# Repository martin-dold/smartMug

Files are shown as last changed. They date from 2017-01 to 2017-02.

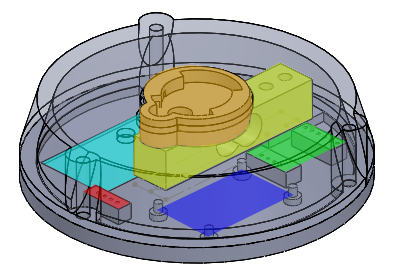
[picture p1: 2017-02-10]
development/src/sensor/3d_modell Kopie.png

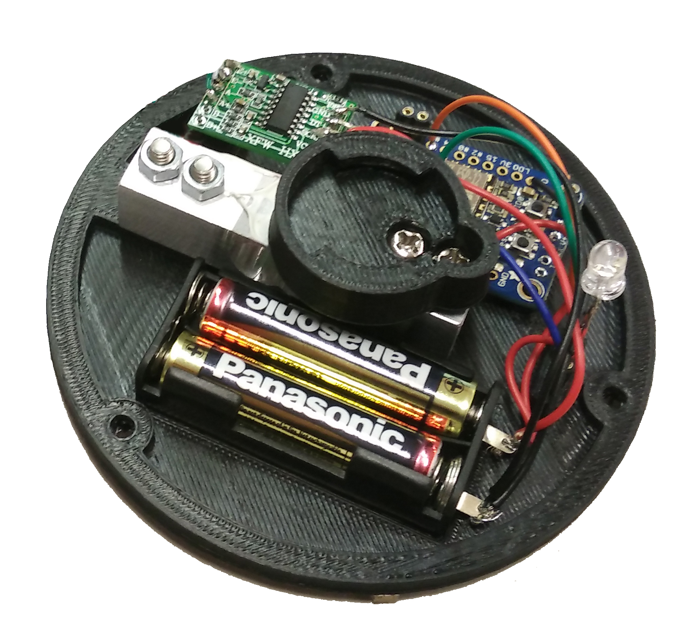
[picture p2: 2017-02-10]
Organization/SequenceDiagram/IMG_20170131_155303 Kopie.jpg

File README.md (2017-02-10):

# SmartMug
This is the repository for the SmartMug project.

The intention of the project is to turn a standard mug into a SmartMug by mounting the developed
SmartMug case on the bottom of the mug.
Using the developed Android App, the user can now connect to his mug.
Once the wireless connection is established, the following services are available:

- Ordering via app: the SmartMug changes its color to signal the waitress
that the user wants a new drink, reorder the same drink, asks for the bill or has no request at all.
- Monitor the current filling level of the mug within the app.
- Play two different drinking games.
- Entering personal data to display user statistics, e.g. blood alcohol level.

# Project Startup and History

This chapter describes initial considerations at project startup that finally lead to the developed SmartMug.
The documentation of the latest release starts in section [Architecture](#architecture).

## Initial Research and Related Work

At start of the project, the team started research on smart mug applications and required technologies.
Besides others, the task was to address the following two main questions:

- Do applications regarding smart liquid level sensing already exist?
- Which technology can be used for smart liquid level sensing?

With regards to the first question, two interesting papers are found.

The project **"Lover's cup"** [1] connects two spatially separated cups via wireless network to the internet.
This remote connection "enable people to share the time of drinking with someone they care about in different places.
Using a wireless connection, an otherwise ordinary pair of cups becomes a communication device,
amplifying the social aspect of drinking behavior" [1].
However, the focus of the paper is the social aspect of drinking rather than the technologies required to build the device.

The project **"Wireless Liquid Level Sensing for Restaurant Applications"** [4] is more of interest for the SmartMug project
as it targets a similar application: "Since restaurants often make much of their profits on drinks, it is critical for servers
to offer refills in a timely fashion. We propose wireless liquid level sensing glassware to aid in this task." [4]
Though the motivation for the project is a more economical aspect, the paper describes
the technologies and especially the liquid level sensing in detail. This project solved the liquid level sensing by
capacitive sensing.
In fact, the paper aims to the same application as the SmartMug.
However, the project was founded in 2002 and technologies vastly enhanced since then. This is the main reason to still
develop the SmartMug using state-of-the-art technologies like low-power optimized wireless modules and smartphones.

With regards to the question about liquid level sensing, the research identified:

- In industry, the focus relies on measuring the liquid flow into or from a container whenever possible rather than measuring the
level of the container itself. Examples are pipette in biology or dosing pumps as medical devices.
- If the liquid level shall be measured within the container, a floating gauge is typically used, e.g. like in car tanks.
However, this solution does not fit to the SmartMug project because of hygienic reasons and general user acceptance as
drinking the liquid in the SmartMug shall be possible and nobody expects a floating gauge in his or her drink.
- An appropriate technology is used by the project **"Wireless Liquid Level Sensing for Restaurant Applications"** [4]
that uses capacitive sensing. Additionally, two application reports give detailed insight into this technology [2] [3].
- If the weight of the mug is known in advance, the liquid level can be measured by weighting the mug including the liquid.
The SmartMug project finally used this technology.

## Hardware and Software Selection
One of the first steps at project startup was to define the required hardware and software components.
Constraints are:

- A wireless protocol that fits for battery powered nodes.
- A wireless protocol that allows a huge number of nodes within network, as there are a lot of mugs within a restaurant or bar.
- A wireless communication module that allows a battery powered application to be attached to the mug.
It should be possible to easily run the previously defined wireless protocol.
- The SmartMug user should easily connect to its mug, even with its own smartphone.

### Wireless Protocol

In the very first evaluation step, the following wireless protocols were considered:

1. IEEE802.11 Wireless LAN 
2. IEEE802.15.4 Zigbee
3. Bluetooth (Low Energy)
4. 6LoWPAN

The Zigbee as well as the 6LoWPAN protocol fit very well with regards to the power consumption constrain:
Both protocols are specialized for battery powered nodes as they both are designed for this application purpose.
Drawback of these protocols is the missing connection to the users smartphone: 
By default, none of these protocols are supported by any state-of-the-art smartphone, that typically supports Wireless LAN and Bluetooth.
Therefore, communication to the smartphone requires a gateway node that forwards messages between the 
SmartMug and the smartphone.
Due to this disadvantage of requiring an additionally device for network translation,
the protocols Bluetooth and Wireless LAN are short-listed.

Finally, the focus changed to Wireless LAN as:

- it is fully supported by almost all smartphones, even older ones,
- it easily allows to run well-known protocols such as TCP/IP or UDP on top for applications data exchange,
- it allows a huge number of mugs to be connected to the same network,
- a lot of today's restaurants and bars already provide a Wireless LAN network to the customers.
This would allow to reuse existing restaurant infrastructure for future SmartMug services directly connected to the bar.
- the universities laboratory provides a Wireless LAN module in-house that states promising power consumption in the documentation.

### Wireless LAN module

As a result, the low-power Wireless module [ESP8266](http://espressif.com/en/products/hardware/esp8266ex/resources "ESP8266") was chosen.
It meets the low-power requirement, has sufficient GPIO pins for the connection to the liquid level sensing unit 
and provides a huge variety of software development kits (SDK), e.g. NodeMCU (Lua-based), Arduino and MicroPython.
A full list of available SDKs is available [here](http://www.mikrocontroller.net/articles/ESP8266 "ESP8266 SDKs").

In the end, Arduino was chosen as it is open-source and provides full library support for Wireless LAN, TCP/IP, Multicast DNS
and even for the HX711 load cell that was chosen for liquid level sensing.

### Smartphone App

To allow the SmartMug user to connect to the mug, a smartphone app shall be developed. 
For the first prototypes, it was defined to develop an app for Android smartphones.
Development of an iPhone app was seen as future extension to the project.

# Source Code Documentation
The source documentation is hosted on GitHub pages.
Click [here](https://martin-dold.github.io/smartMug/ "Source Code Documentation") to browse the source code documentation.

# Architecture
Within this project the following components are involved:

- **Mug**: Usual mug that holds your drink.
- **SmartMug**: Extension to your make your mug smart.
- **Android app**: Connects to your SmartMug and provides the service(s).
- **Wifi access**: SmartMug and Android App require a Wireless LAN network to communicate.

## Liquid Level Sensing

Initially there were two different approaches for liquid level sensing. Finally the decision was pro weight measurement, because:

- Capacitive measurement requires bent or flexible copper plates to be mounted on a circular surface. This material was not available in a suitable amount time. 
- At the beginning the team was not sure, if such a circuit could be developed in time.

The chosen method of liquid level sensing is weight measurement. This task is accomplished by a load cell, an amplifier and an analog-to-digital converter.

- **load cell**: Contains four strain gauges, that build a Wheatstone Bridge. The differential output voltage can be measured by an amplifier.
- **HX711**: Uses a built in amplifier and ADC. No further circuits are required.

## Arduino

Wireless module [ESP8266](http://espressif.com/en/products/hardware/esp8266ex/resources "ESP8266") 
is programmed using open-source Arduino SDK. The firmware is composed of several Arduino files.
Each of them contains a separate software unit/module. 
For a complete list of software modules and its implementation details, check out the Arduino chapter
of the [Source Code Documentation](https://martin-dold.github.io/smartMug/ "Source Code Documentation").

Most important software modules are:

- **Wifi:**  
Uses Arduino ESP8266 Wifi library to establish a Wifi connection.
After startup, the SmartMug scans its environment for the Wireless LAN SSID "*smartmug*". A password for WPA2 is required.
- **TCP:**  
Uses Arduino TCP library to create a server socket and listen on TCP port 8080 for incoming connection requests.
- **HX711:**  
Uses HX711 library to measure the weight using HX711 load cell.
- **Over-the-air Update:**  
Uses Arduino ESP8266 OTA library to provide firmware update over-the-air.

### Pin configuration and functions

The following table lists the pins that are connected to the microcontroller.

| Pin | Function |
| --- |:---:|
| 13 | RGB-LED Red |
| 5 | RGB-LED Green |
| 12 | RGB-LED Blue |
| 14 | HX711 scale: DOUT |
| 16 | HX711 scale: PD_SCK |
| 21 | UART Tx data |
| 22 | UART Rx data |

## Android App

This section contains a brief overview of the Android App architecture and its main features.
For more details check out the [Source Code Documentation](#source-code-documentation).

- Target API level: 24.
- Android version: 7.
- Architecture of the SmartMug App, first view is Main Activity:
    - Connection to Mug activity -> build connection to SmartMug via manuell input of the IP address or via bar code scanner.
    - Statistics activity -> collects statical data of the user.
    - Order activity -> allows to call the waitress, reorder the same drink or ask for the bill.
    - Personal Data activity -> allows the user to enter personal data information to calculate statistics like blood alcohol level.
    - Games activity -> allows to the user to play drinking games.
    - TCPClient class -> create new TCP Connection for sending (e.g. re-order) and receiving (e.g. filling level).
    - MugContent class -> handle received messages from the SmartMug.
    - NSDHelper class -> scans the network for smartmug mug services using mDNS.

## SmartMug case manufacturing

The case manufacturing contains two main tasks namely the case itself and the mounting parts, that are connecting the actual mug with the load cell. All the parts are modelled in SolidWorks 2013 and are printed via the MakerBot Replicator X2 3D-printer.

The case itself has a bottom part, where all the components are mounted. The mounted elements are:
- Load Cell
- Adafruit Huzzah ESP8266 microcontroller
- Hx711 ADC and Amplifier
- RGB LED
- Battery case for AA batteries.

The second part is a bayonet mount, with a female and a male part. These are used to connect the mug the load cell.

# Communication

This chapter explains the communication schemes and protocols that are used within this project.

## TCP/IP

The communication between the SmartMug and the Android App is based on TCP/IP using Wireless LAN according to IEEE802.11b/g standard.
Therefore, the Android device and the SmartMug must be connected to the same wireless network to allow communication between both.

The SmartMug acts as TCP server that is continuously waiting for incoming connections right after startup.
Once a TCP connection is established successfully, the mug provides updated liquid level values once a second.
The mug publishes its service to the network using [Multicast DNS](#multicast-dns).

The Android App acts as TCP client connecting to the SmartMug.

## Multicast DNS

The SmartMug publishes its service through "Multicast DNS" (mDNS) including the following properties:

- *Service name*: smartmug
- *Service type*: \_smartmug.\_tcp

The Android App is listening for providers of the smartmug service type. Using the identifier read from the SmartMug bar code,
the app is able to select the correct mug to connect to out of the list of available mugs within the network.

## SmartMug Protocol

The SmartMug Protocol is invented for bidirectional communication between the SmartMug and the Android App. It is used on top of the TCP protocol to format the byte stream.
It follows the basic principle of < TAG >< LEN >< Value > and is implemented as shown in the following graph:

```
+-----------+------------+----------------+----------------+
|           |            |                |                |
|    TAG    |   Length   |      Value     |  End of Frame  |
|           |            |                |                |
+-----------+------------+----------------+----------------+

   1 byte       1 byte        n bytes           1 byte
```

Multi-byte fields are transported with most significant byte (MSB) first.

The following tags are currently defined:

- Tag = **0x01**: (SmartMug to Android App)  
  Sensor Data: Weight (in gram)
- Tag = **0x02**: (Android App to SmartMug)  
  LED Set Color using color codes transported as value:  
  - Off:   0
  - Red:   1
  - Green: 2
  - Blue:  3
  - White: 4
- Tag = **0x03**: (Android App to SmartMug)  
  Tare SmartMug scale to '0'

Accordingly, an example of a sensor data frame is:

```
+-----------+------------+----------------+----------------+
|           |            |                |                |
|   0x01    |    0x02    |     0x017A     |      0x0A      |
|           |            |                |                |
+-----------+------------+----------------+----------------+

   Sensor       Length          378g             '\n'
    Data
```

# Outlook

This chapter lists further features and ideas in general that can be added to the project.

## Connect to the Restaurant

A connection between SmartMug and the restaurant would allow the barkeeper to monitor the customers mugs using live data, i.e.
the barkeeper is able to detect when to serve which guest based on the SmartMug data.
Furthermore, this allows the customer to directly place an order to the barkeeper via wireless connection.

## Payment via SmartMug App

Once the connection to the restaurant is established, one may advance the SmartMug App to allow a digital payment method for the drinks.

## Health monitoring

The data the SmartMug App currently collects (sex, weight and total amount of liquid) allows to offer further services like health monitoring.
The SmartMug App can detect when the user did not drink for some hours and can give warnings to ensure that a patient drinks enough liquid during a day.

## Security

The current security mechanism relies on the encryption mechanism used by the wireless network (e.g. WPA2) both Android app and SmartMug are connected to.
The communication between the SmartMug and the app is neither authenticated nor secured on a higher level.
A new feature might be using a TLS protected channel or (at least) an AES encrypted communication between the devices.
However, it should be considered that TLS is heavy computational work for small microcontrollers.
This holds true especially for battery powered device like the SmartMug.
Computing TLS sessions will surely have an impact on the battery life time of a SmartMug.
Still, AES encryption is state-of-the-art even for small microcontrollers as HW acceleration is feasible and allows to
reduce power consumption for battery powered devices.

Therefore, application layer security using AES encryption appears reasonable.

# References

- [1] Lover’s Cups: Drinking Interfaces as New Communication Channels, Chung et al., 2006, [Link](http://dl.acm.org/citation.cfm?id=1125532&dl=ACM&coll=DL&CFID=725409781&CFTOKEN=29915740 "Link to Paper")
- [2] Ultrasonic Sensing Basics for Liquid Level Sensing, Flow Sensing, and Fluid Identification Applications,  
Texas Instruments, 2015, [Link](http://www.ti.com/lit/an/snaa220a/snaa220a.pdf "Link to PDF")
- [3] FDC1004: Basics of Capacitive Sensing and Applications, Texas instruments, 2014, [Link](http://www.ti.com/lit/an/snoa927/snoa927.pdf "Link to PDF")
- [4] Wireless Liquid Level Sensing for Restaurant Applications, Dietz et al., 2002, [Link](http://www.merl.com/publications/docs/TR2002-21.pdf "Link to Paper")
- [5] Datasheet of Hx711 [Link] (http://www.ti.com/lit/an/snoa927/snoa927.pdf "Link to datasheet")

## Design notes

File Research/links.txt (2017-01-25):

https://www.teco.edu/research/mediacup/

Hier mal etwas interessantes:
http://www.merl.com/publications/docs/TR2002-21.pdf

-> "Capacitive Sensing" klingt ziemlich interessant.

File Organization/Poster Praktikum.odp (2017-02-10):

## SmartMug The clever way to order

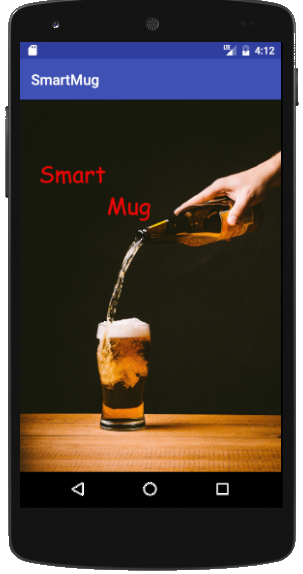
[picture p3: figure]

  Martin Dold, Larraitz Orio,
  Gürkan Karacocuk, Dennis Tritschler

Architecture

Android App: Connects to the SmartMug

Wifi access: Wireless Communication

Mug: Standard Mug

Smart Mug: Extension to make your mug smart

Functions

Connection to mug via bar code reading

Liquid level sensing via weight (HX711 circuit)

Drinking statistic analysis via app

Interactive drinking games via app

Waitress communication by changing mug color

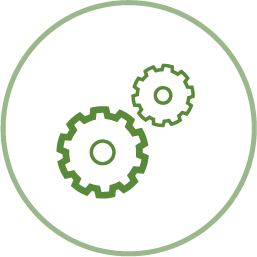
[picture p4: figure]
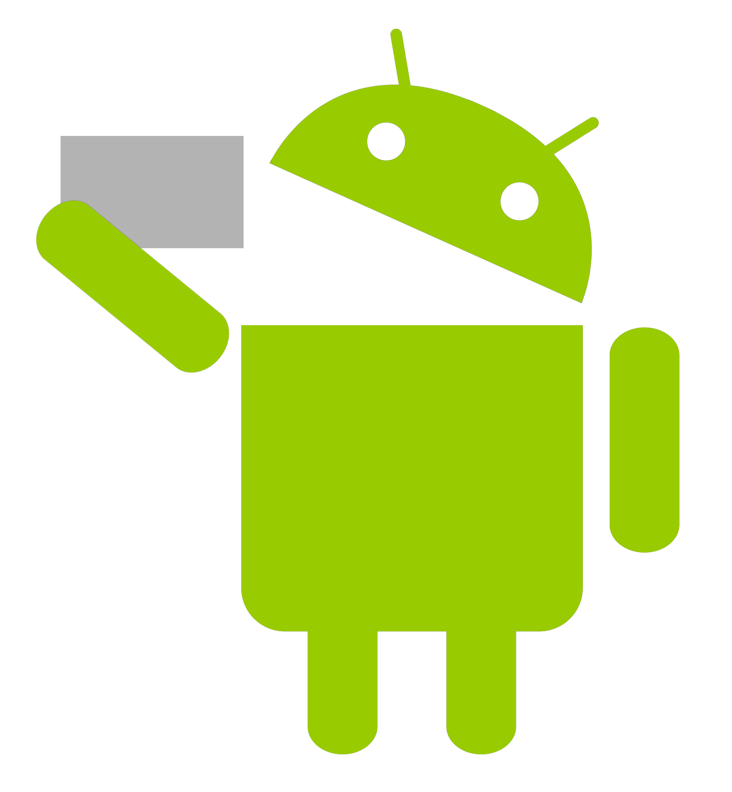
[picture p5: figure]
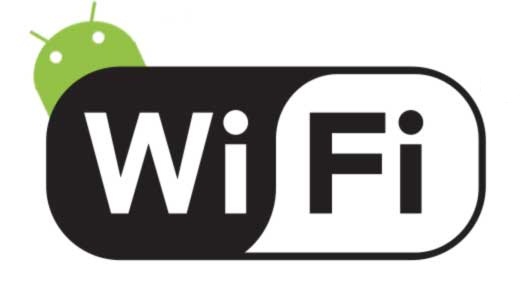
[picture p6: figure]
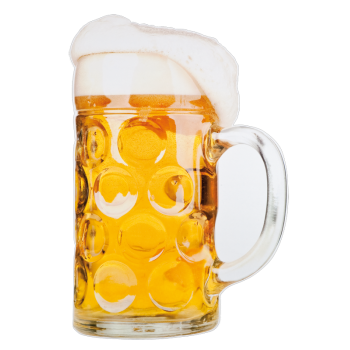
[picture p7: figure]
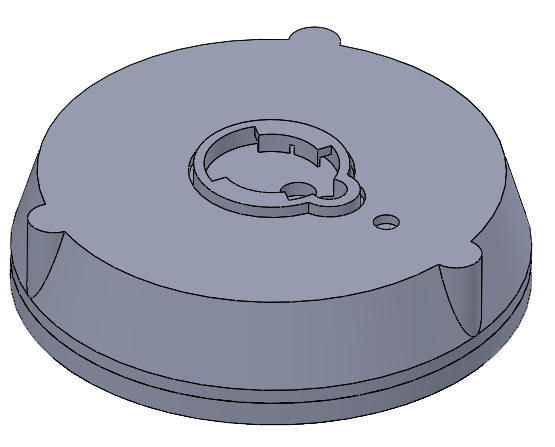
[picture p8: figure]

SmartMug

SmartMug App

HX711

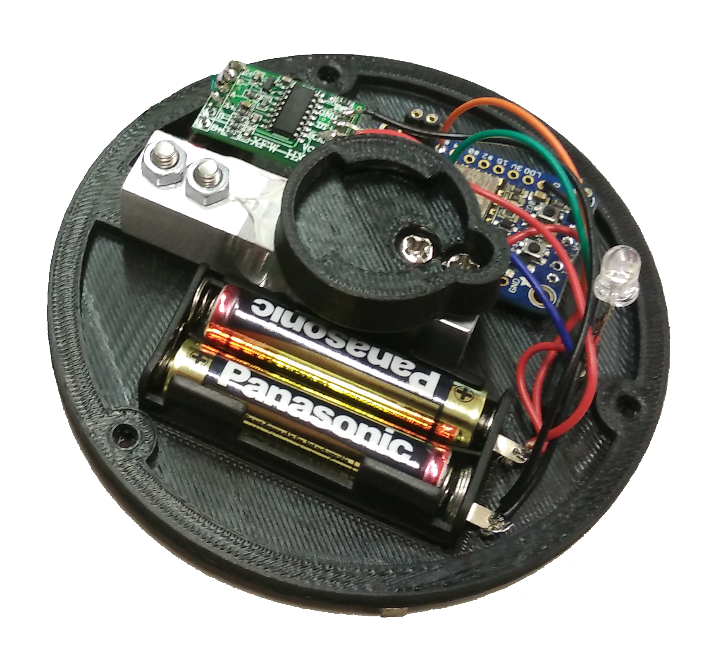
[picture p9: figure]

Bayonet mount

Connect to your

SmartMug via Bar Code

or by entering

manuell the IP Adress

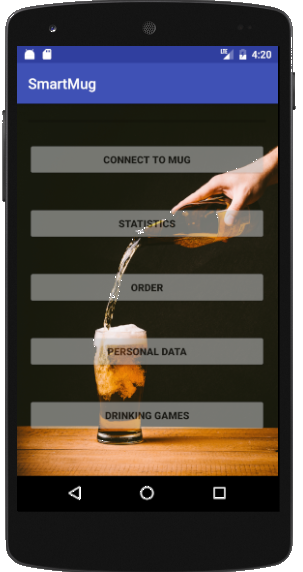
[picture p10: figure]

Load cell

Adafruit Huzzah

Display some

statistics like promile

RGB-LED

Batteries

Enter your personal Data

for some statistics


Order via SmartMug

Case

Play some drinking

games

Connection

SmartMug Protocol

TCP/IP → Wireless LAN according to

IEEE802.11b/g standard

Multicast DNS:

Service name: smartmug

Service type: _smartmug._tcp

Tag 1byte | Length 1byte | Value n bytes | End of Frame 1 byte

Sequence diagram

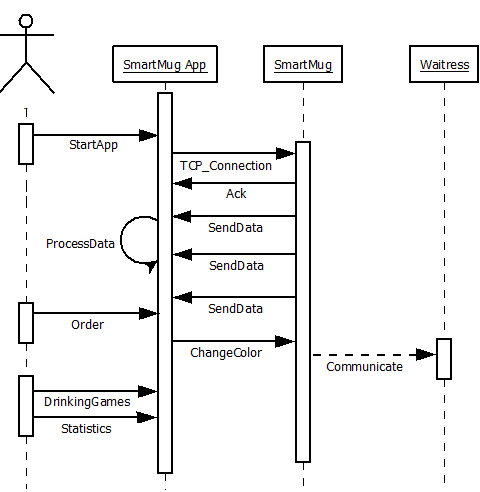
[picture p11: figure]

Outlook

- Connection to the barkeeper → Live data for the barkeeper, direct re-order function

- Payment via app

- Capacitive measurement instead of weight

- Connection between taps and SmartMug for automated and exact measurement of the filling level

More Details under:

https://github.com/martin-dold/smartMug

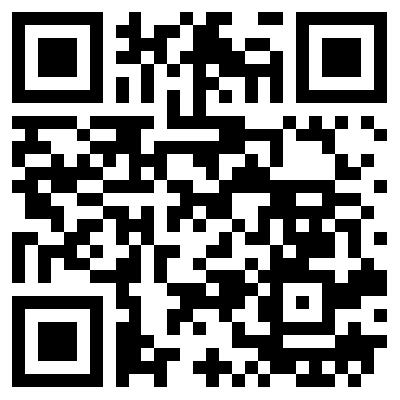
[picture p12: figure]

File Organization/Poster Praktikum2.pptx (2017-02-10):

## SmartMug The smart way of drinking


- Martin Dold, Larraitz Orio,
- Gürkan Karacocuk, Dennis Tritschler

Architecture
Android App: Connects to the SmartMug
Wifi access: Wireless Communication
Mug: Standard Mug
Smart mug: Extension to make your mug smart

Functions
Connection to mug via bar code reading
Liquid level sensing via weight (HX711 circuit)
Drinking statistic analysis via app
Interactive drinking games via app
Waitress communication by changing mug color

SmartMug

HX711

SmartMug App

Batteries

Load cell


Bayonet mount


RGB-LED

ESP8266 module

Glass fill level

Connect to SmartMug
via Bar Code or by
entering the IP Adress

Enter your personal data
for some statistics

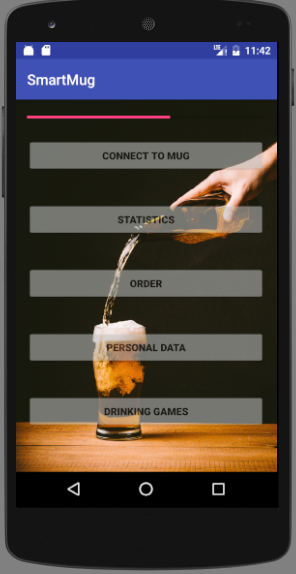
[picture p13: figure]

Display statistics
e.g. Blood alcohol level

Order via SmartMug

Case

Play drinking games

Connection
SmartMug Protocol
TCP/IP → Wireless LAN according to
IEEE802.11b/g standard
Multicast DNS:
Service name: smartmug
Service type: _smartmug._tcp

Tag 1byte | Length 1byte | Value n bytes | End of Frame 1 byte

Sequence diagram


Outlook
- Connection to the barkeeper → Live data for the barkeeper, direct re-order function
- Payment via app
- Capacitive measurement instead of weight
- Connection between taps and SmartMug for automated and exact meassuring of the filling level

More Details under:
https://github.com/martin-dold/smartMug


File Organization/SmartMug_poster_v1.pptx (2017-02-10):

## Smart Mug Don’t wait for drinks anymore

Martin Dold, Larraitz Orio,
Gürkan Karacocuk, Dennis Tritschler

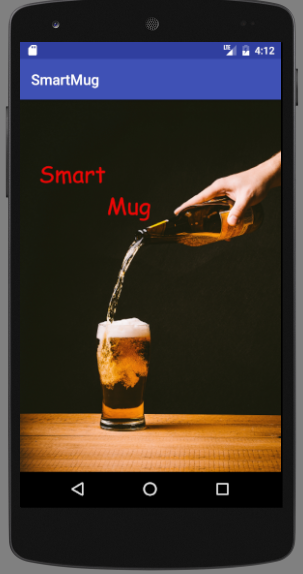
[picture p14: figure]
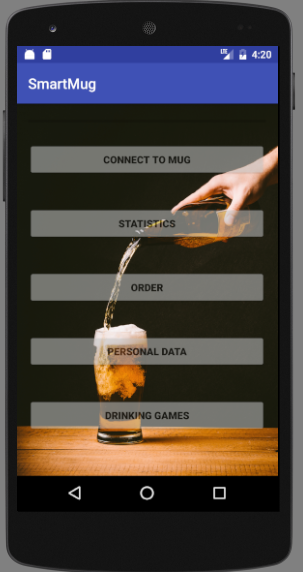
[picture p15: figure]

Outlook
- Connection to the Barkeeper
- Interactive Drinking Games
- Payment with app
- Capacitive measurement

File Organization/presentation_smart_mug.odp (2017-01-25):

## Smart Mug

Presentation 1: Concept

Dennis Tritschler, Guerkan Karacocuk, Martin Dold

Winter Term 2016

## Motivation

- I don't want to wait for the waiter/waitress to order new beer!

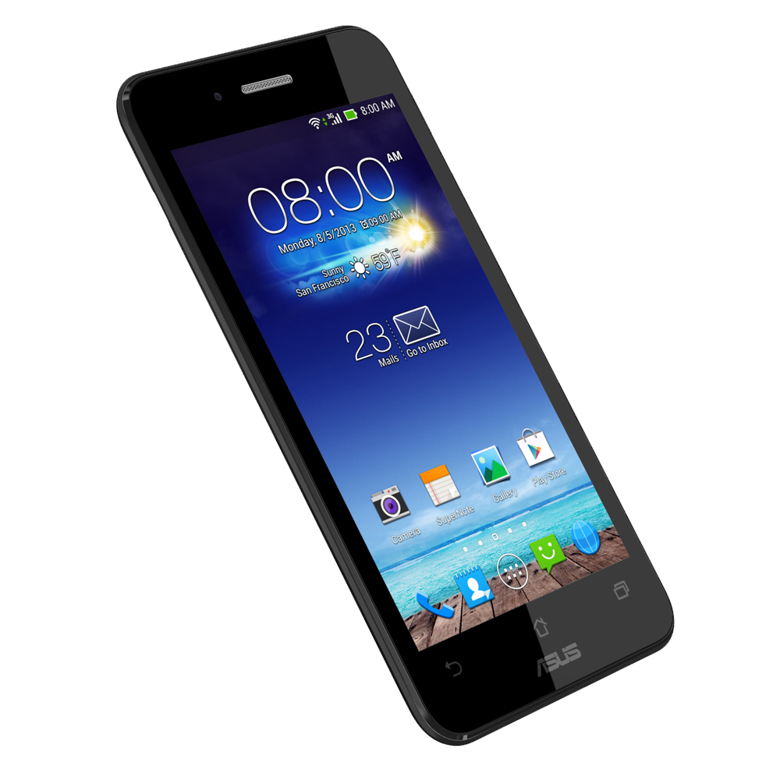
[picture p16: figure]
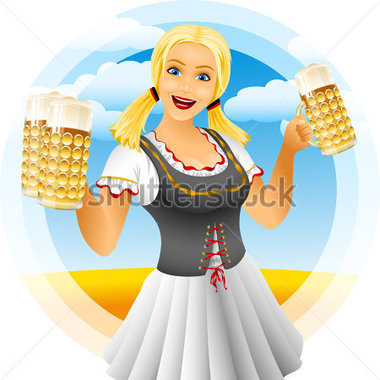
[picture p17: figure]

## Plan A

- Beer level sensing
  - By weight, by capacitive sensing, …
- Connect mug with smartphone
  - Bluetooth LE
  - Barcode, RFID
- Order by app and color of mug
- Live data for bar keeper
- Interactive drinking games

## Plan B

- Measure beer level
  - By weight, by capacitive sensing, …
- Connect mug with smartphone
  - Bluetooth LE
  - Entering mug ID into app
- Order by color of mug

## Plan C

- Connect mug with smartphone
  - Bluetooth LE
  - Entering mug ID into app
- Order by color of mug

## Plan D – Worst case

If neither wireless communication nor measurement works …

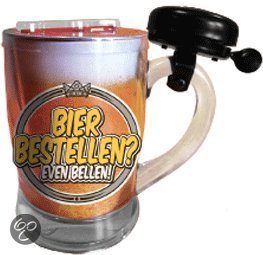
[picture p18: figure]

## Next steps / work plan

15.11. | Present (initial) selection of HW: - Sensor(s) - Bluetooth module
22.11. | Start SW implementation sensor reading, BLE connection Start HW schematic, layout
29.11. | Continue …
6.12. | Prepare for mid-term presentation: SW: sensor reading, BLE connection HW: schematic, layout ready

## Next steps / work plan

20.12. | First HW prototype ready
10.01. | Extend SW parts: order by app
17.01. | Extend SW parts: Connect to bar tender, display filling level
24.01. | Debugging / bug fixing
31.01. | Finalize debugging / bug fixing Report / Poster
07.02. | Project finalization

## Related work

- Wireless Liquid Level Sensing for Restaurant Applications (iGlassware)

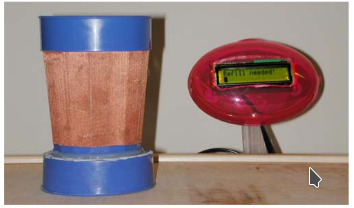
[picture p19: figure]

## Related work

- Lover’s Cups: Drinking Interfaces as New Communication Channels

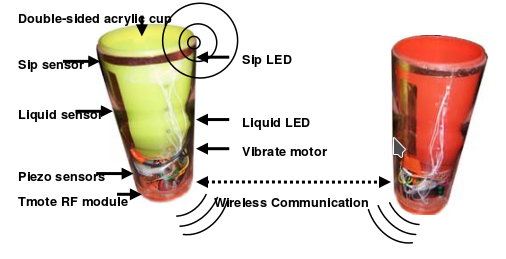
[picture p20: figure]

## Appendix

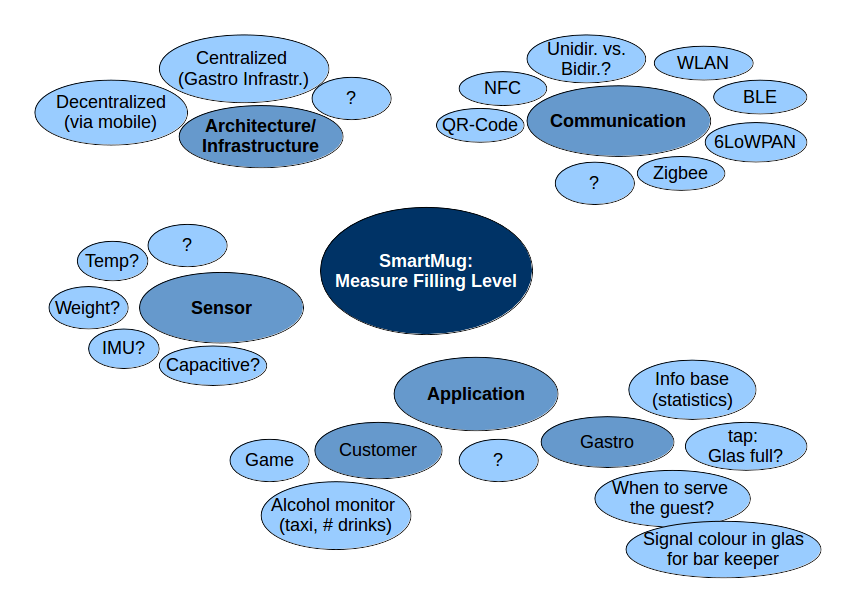
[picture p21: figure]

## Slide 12

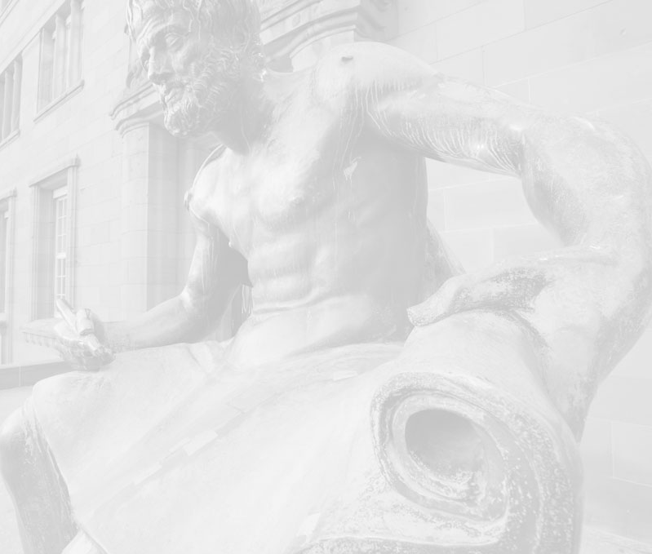
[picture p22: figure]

  Dieses Folienlayout bitte nur verwenden, um großformatige Abbildungen wie in diesem Beispiel zu zeigen.
  Es ist nicht für Texte etc. vorgesehen.

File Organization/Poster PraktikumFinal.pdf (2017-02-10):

# SmartMug

# The clever way to order

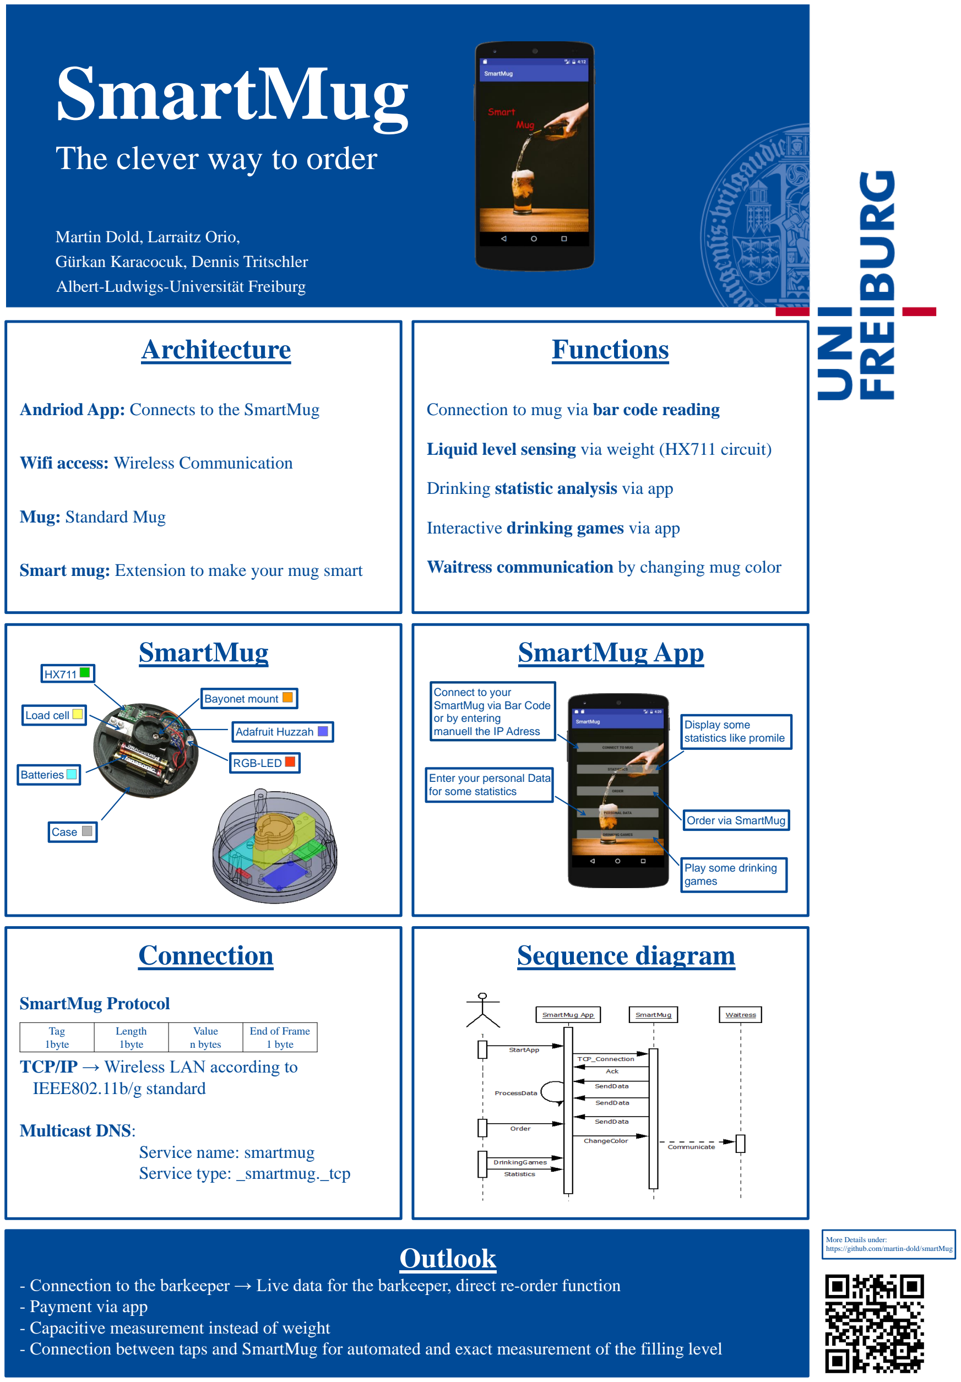
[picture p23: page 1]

Albert-Ludwigs-Universität Freiburg

## SmartMug

Martin Dold, Larraitz Orio,
Gürkan Karacocuk, Dennis Tritschler

## SmartMug App

## Connection

SmartMug Protocol

TCP/IP → Wireless LAN according to IEEE802.11b/g standard

Multicast DNS:
Service name: smartmug
Service type: _smartmug._tcp

## Sequence diagram

## Outlook

- Connection to the barkeeper → Live data for the barkeeper, direct re-order function
- Payment via app
- Capacitive measurement instead of weight
- Connection between taps and SmartMug for automated and exact measurement of the filling level

## Architecture

Andriod App: Connects to the SmartMug

Wifi access: Wireless Communication

Mug: Standard Mug

Smart mug: Extension to make your mug smart

## Functions

Connection to mug via bar code reading

Liquid level sensing via weight (HX711 circuit)

Drinking statistic analysis via app

Interactive drinking games via app

Waitress communication by changing mug color

Connect to your
SmartMug via Bar Code
or by entering
manuell the IP Adress

Order via SmartMug

Play some drinking
games

Display some
statistics like promile

Enter your personal Data
for some statistics

Bayonet mount
Load cell

HX711

Adafruit Huzzah

Batteries

RGB-LED

Case

More Details under:
https://github.com/martin-dold/smartMug

Tag
1byte

Length
1byte

Value
n bytes

End of Frame
1 byte

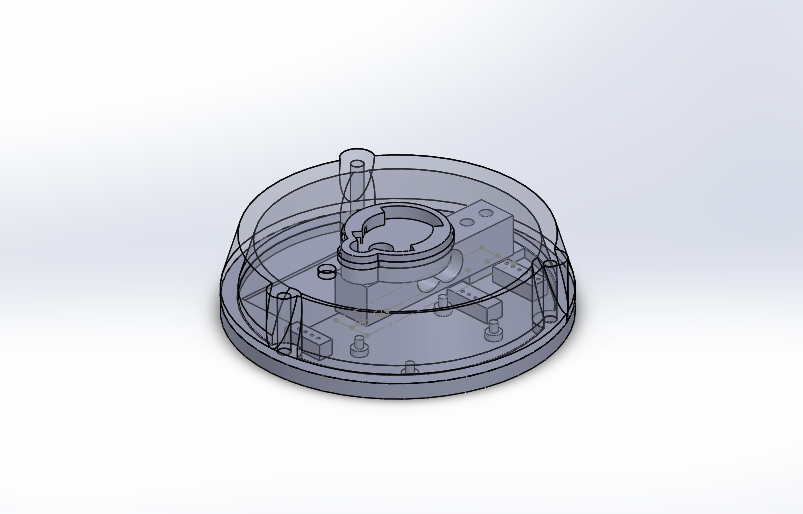
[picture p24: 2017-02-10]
development/src/sensor/3d_modell.PNG

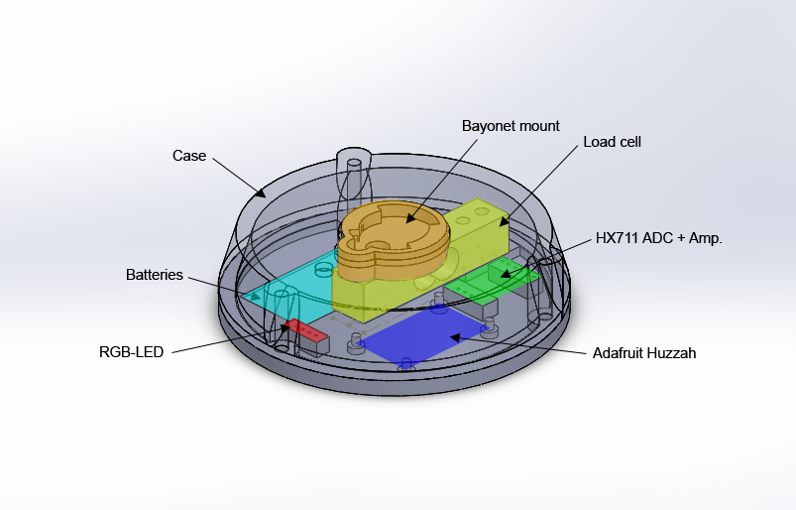
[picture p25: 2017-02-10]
development/src/sensor/3d_modell_gk.png

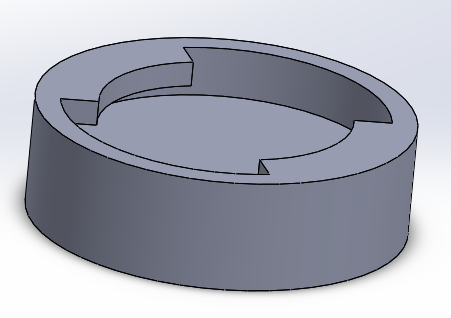
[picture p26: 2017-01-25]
development/src/sensor/gewinde/femalePart.PNG

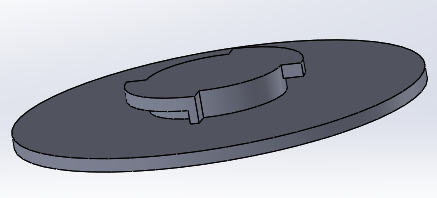
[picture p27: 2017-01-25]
development/src/sensor/gewinde/malePart.PNG

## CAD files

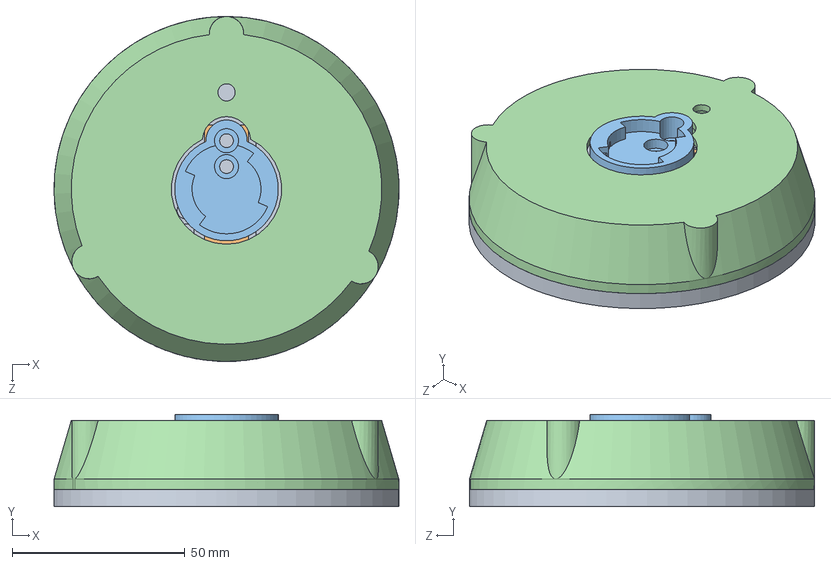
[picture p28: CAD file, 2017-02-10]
development/src/sensor/gehaeuse/gehaeuse.SLDASM
100.0 x 26.7 x 100.0 mm
boden
loadcell
femalePart2
deckel

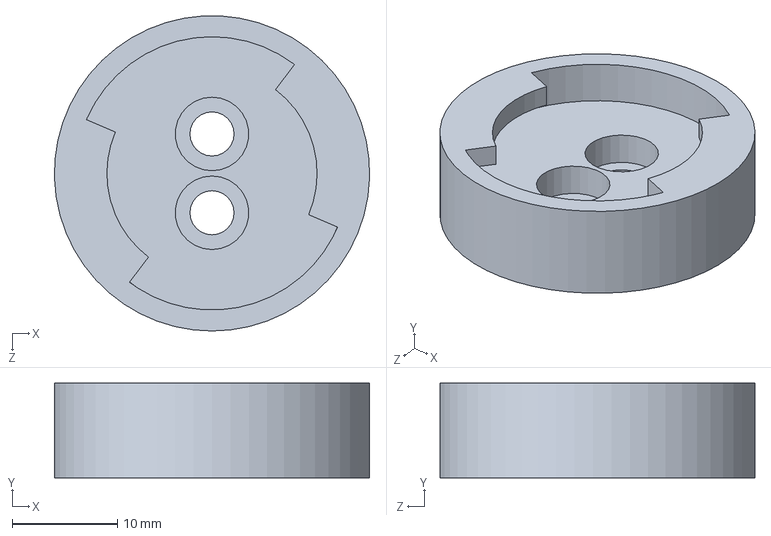
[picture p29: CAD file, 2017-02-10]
development/src/sensor/gewinde/femalePart.SLDPRT
30.0 x 9.00 x 30.0 mm

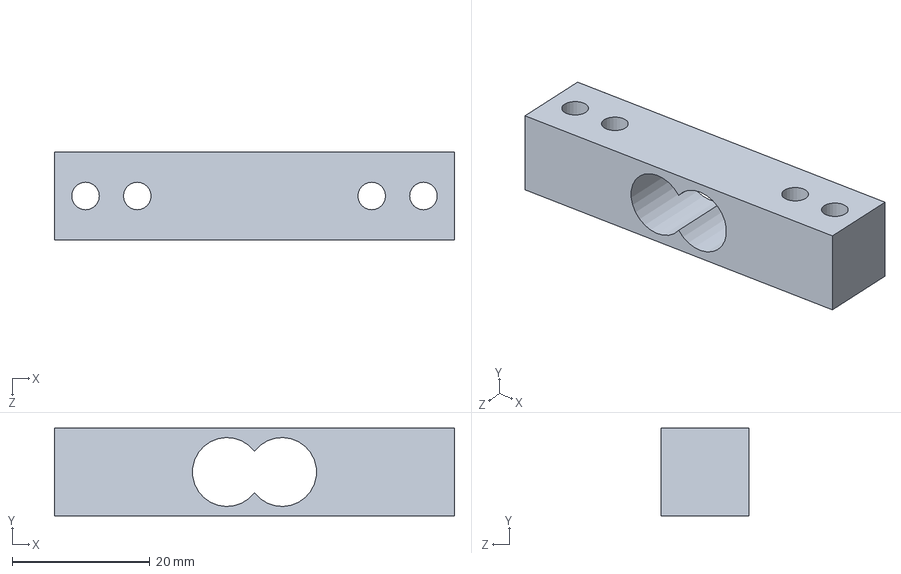
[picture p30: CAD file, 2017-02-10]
development/src/sensor/loadcell.SLDPRT
58.0 x 12.7 x 12.7 mm

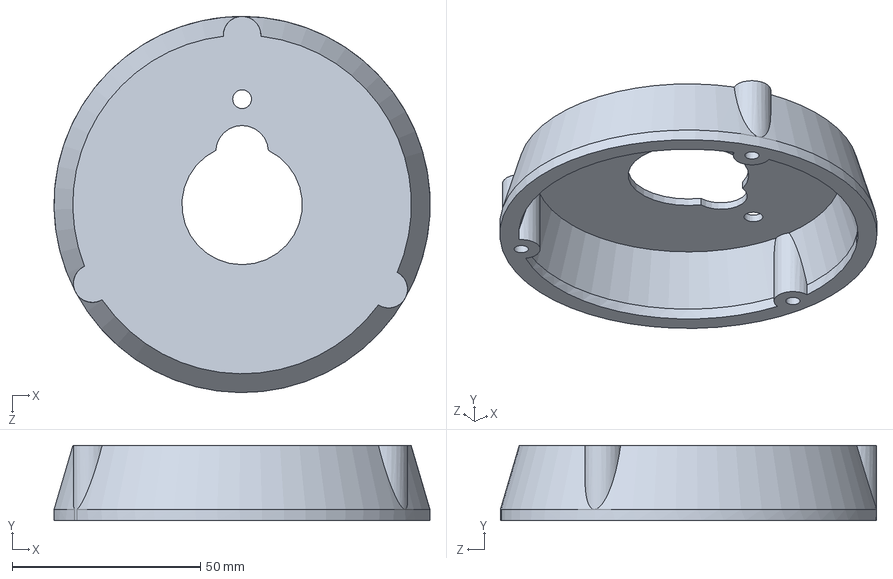
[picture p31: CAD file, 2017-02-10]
development/src/sensor/gehaeuse/deckel.SLDPRT
99.9 x 20.0 x 100.0 mm

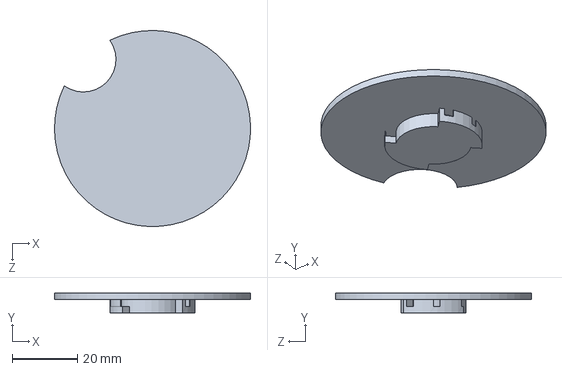
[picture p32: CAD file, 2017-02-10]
development/src/sensor/gewinde/malePart2.SLDPRT
60.0 x 6.00 x 60.0 mm

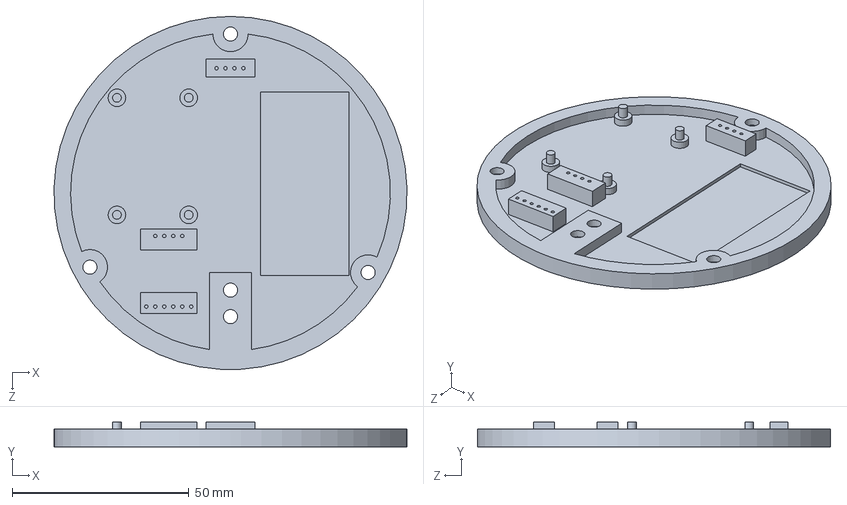
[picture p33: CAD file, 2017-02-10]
development/src/sensor/gehaeuse/boden.SLDPRT
100.0 x 7.00 x 100.0 mm

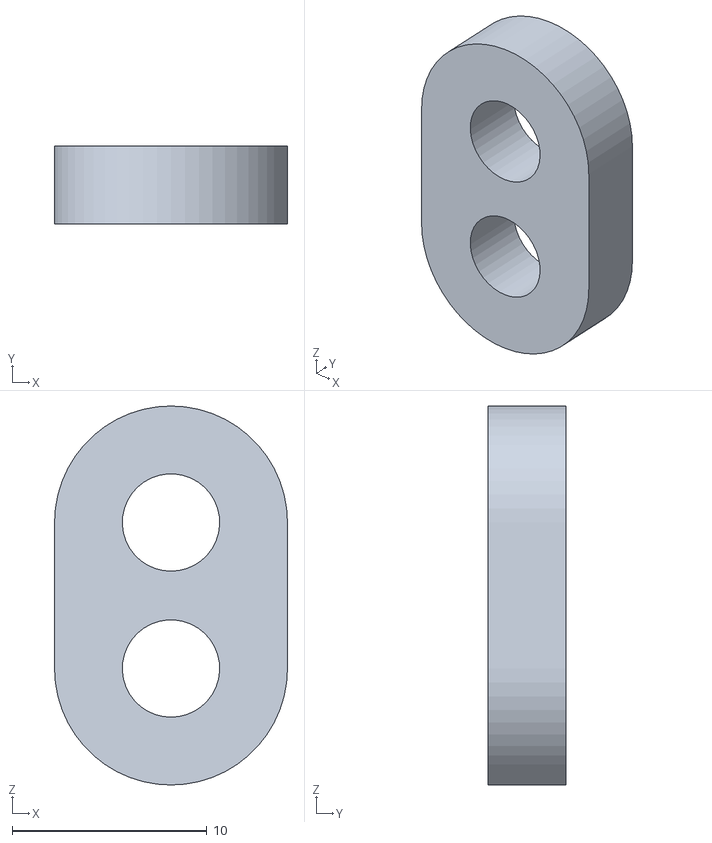
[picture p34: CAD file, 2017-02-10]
development/src/sensor/gewinde/Unterlagscheibe4.STL
12.0 x 4.00 x 19.5

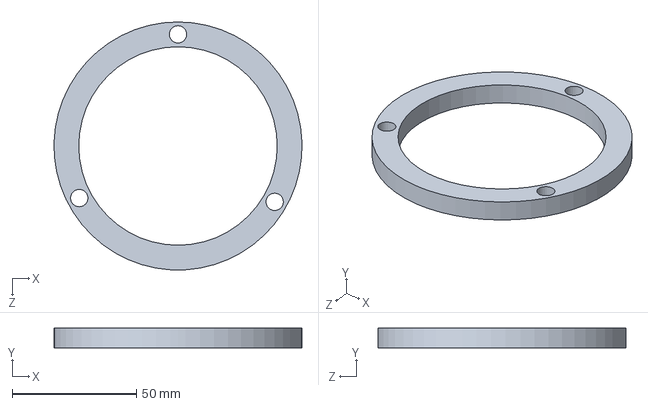
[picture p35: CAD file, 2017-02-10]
development/src/sensor/gehaeuse/ring.SLDPRT
100.0 x 8.00 x 100.0 mm

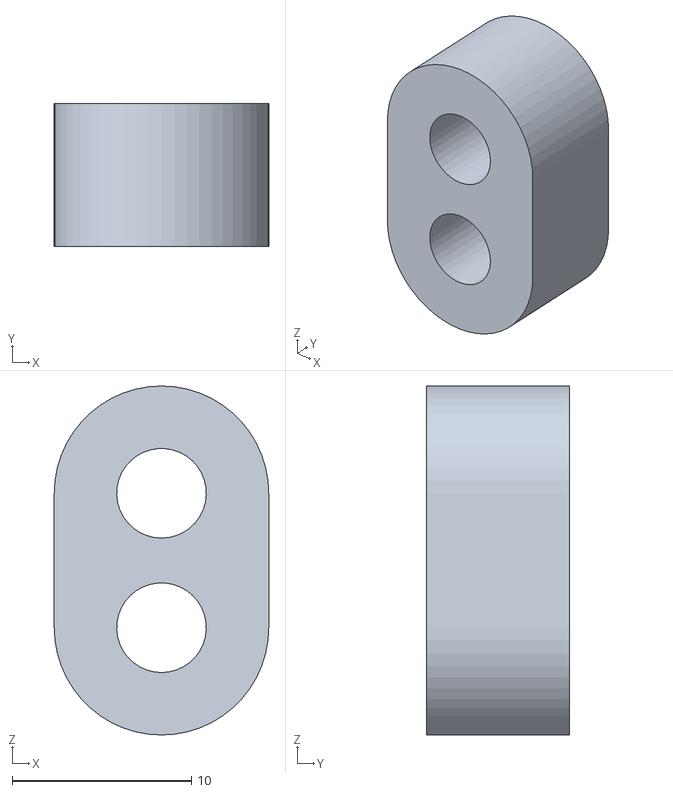
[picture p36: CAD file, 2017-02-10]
development/src/sensor/gewinde/Unterlagscheibe8.STL
12.0 x 8.00 x 19.5

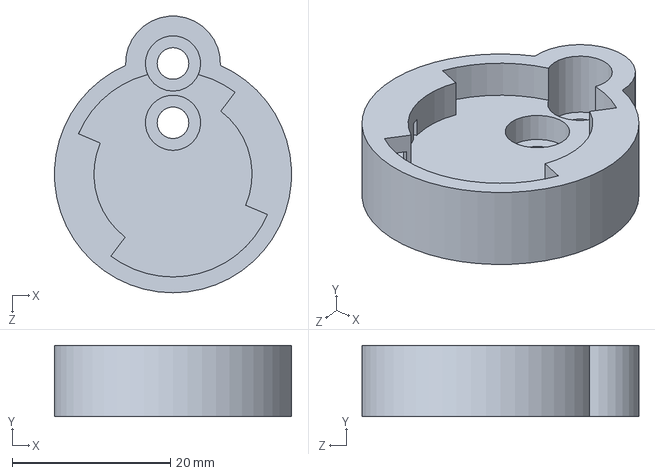
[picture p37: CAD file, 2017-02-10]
development/src/sensor/gewinde/femalePart2.SLDPRT
30.0 x 9.00 x 35.0 mm

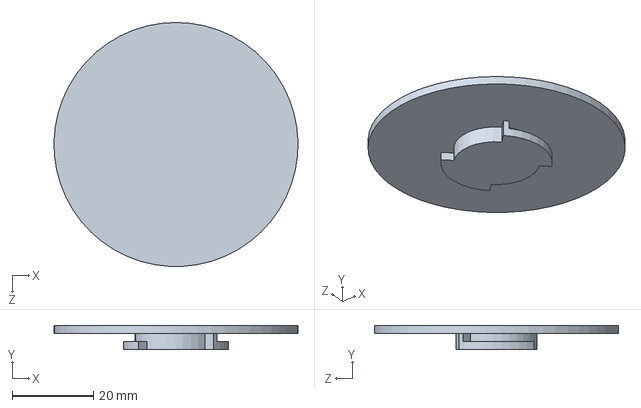
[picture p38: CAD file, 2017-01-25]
development/src/sensor/gewinde/malePart.SLDPRT
60.0 x 6.00 x 60.0 mm

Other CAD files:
development/src/sensor/gewinde/femalePart1.STL
development/src/sensor/gewinde/Unterlagscheibe.SLDPRT
development/src/sensor/gehaeuse/boden.STL
development/src/sensor/gehaeuse/deckel.STL
development/src/sensor/gehaeuse/ring.STL
development/src/sensor/gewinde/femalePart.STL
development/src/sensor/gewinde/femalePart2.STL
development/src/sensor/gewinde/malePart.STL
development/src/sensor/gewinde/malePart2.STL

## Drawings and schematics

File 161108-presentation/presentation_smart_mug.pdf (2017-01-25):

## Smart Mug

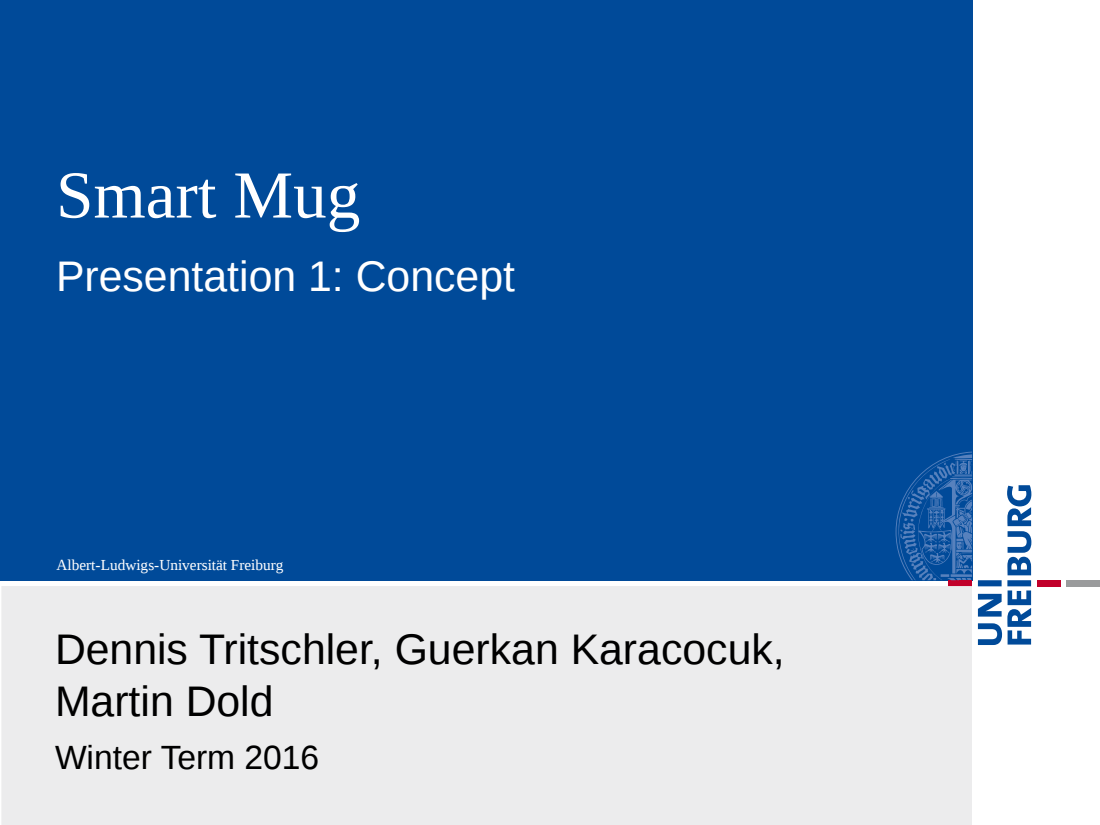
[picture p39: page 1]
Presentation 1: Concept

Albert-Ludwigs-Universität Freiburg
Dennis Tritschler, Guerkan Karacocuk,
Martin Dold
Winter Term 2016

### Motivation

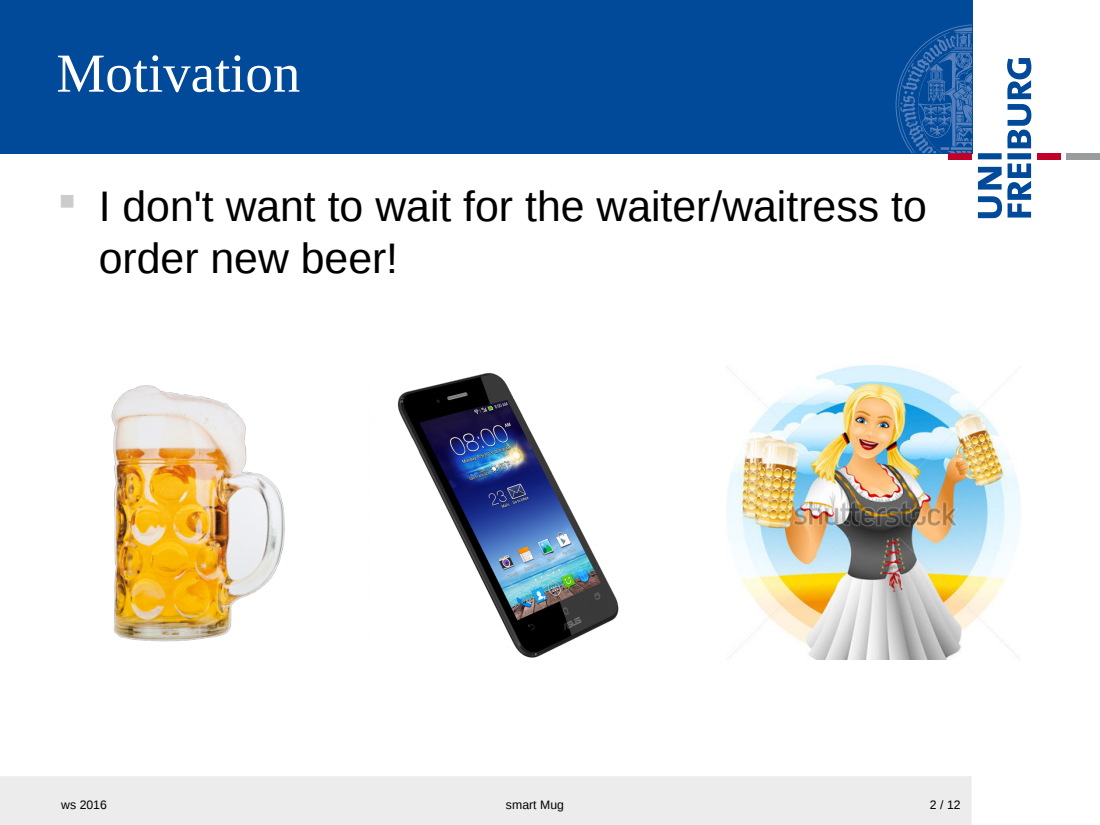
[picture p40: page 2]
smart Mug

§ I don't want to wait for the waiter/waitress to
order new beer!

### Plan A

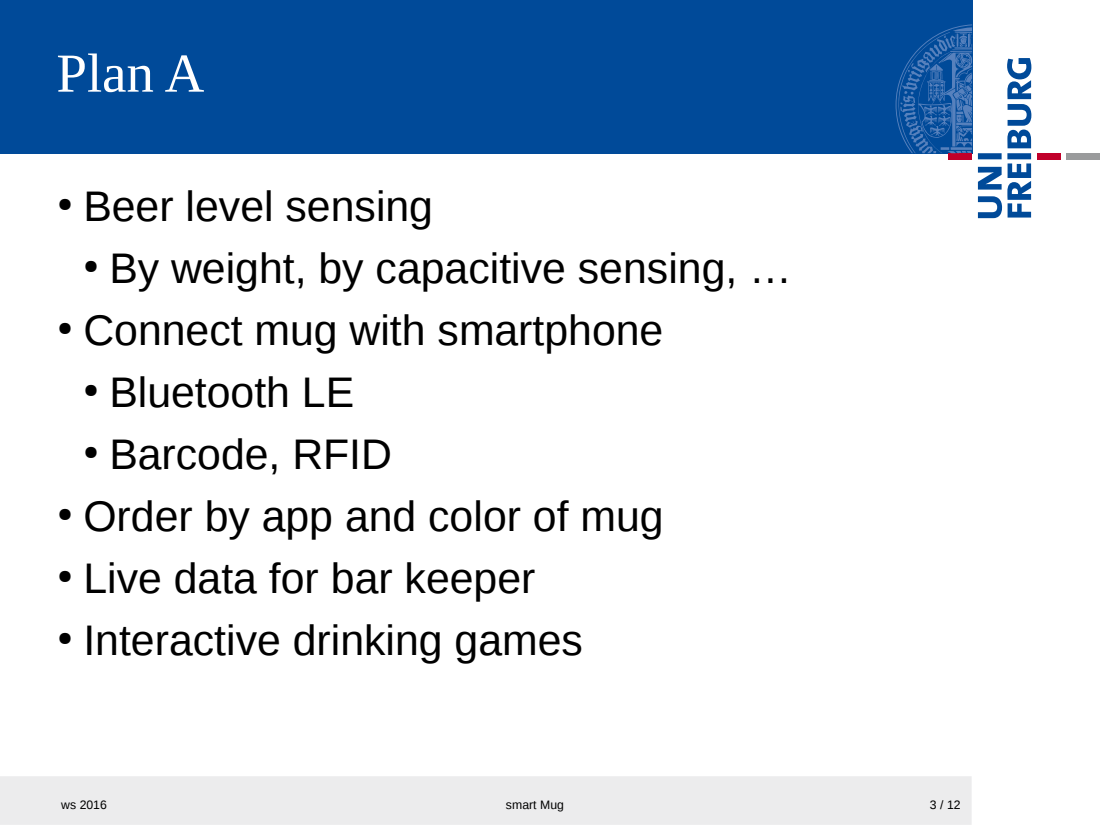
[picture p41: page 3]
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

### Plan B

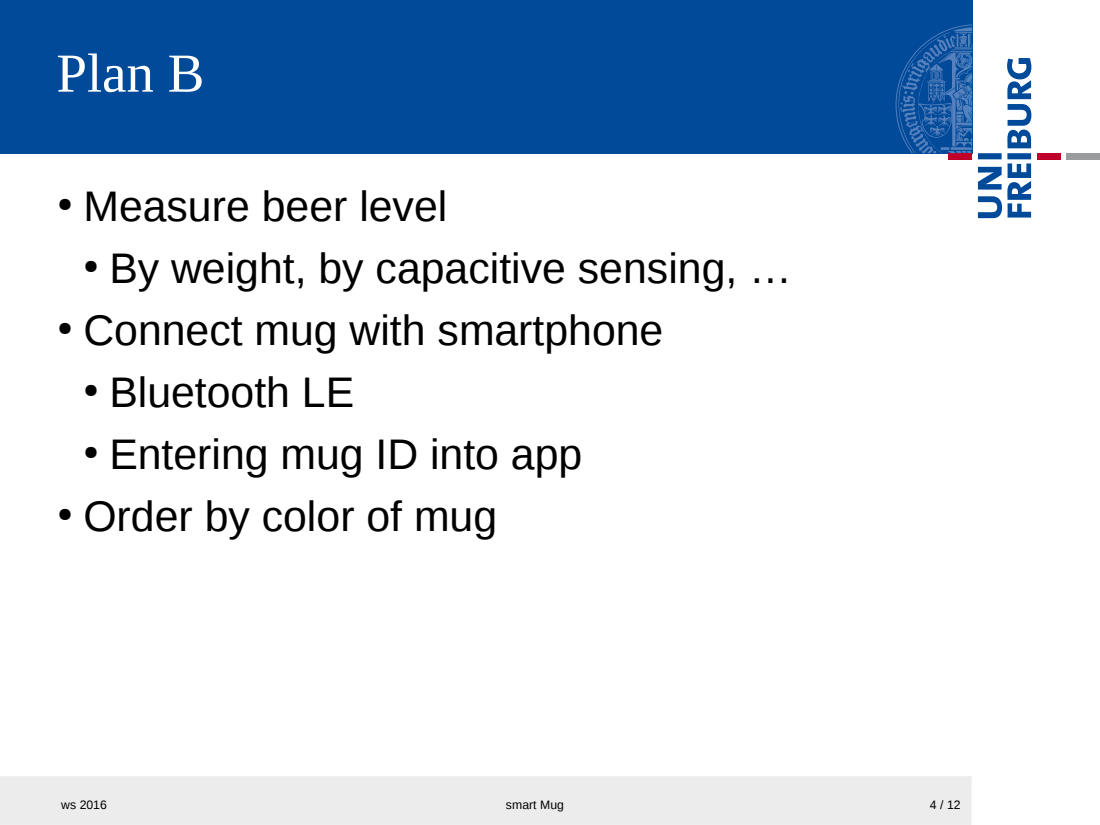
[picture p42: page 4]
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

### Plan C

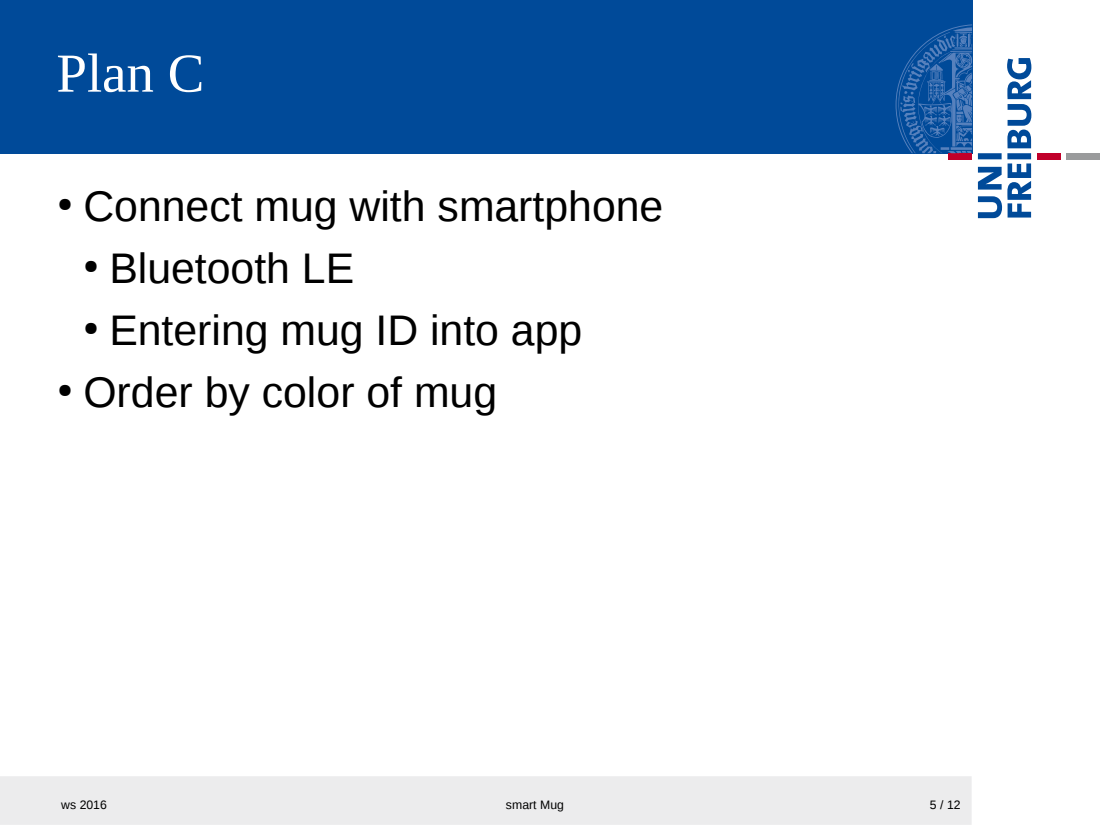
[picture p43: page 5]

● Connect mug with smartphone
● Bluetooth LE
● Entering mug ID into app
● Order by color of mug

### Plan D – Worst case

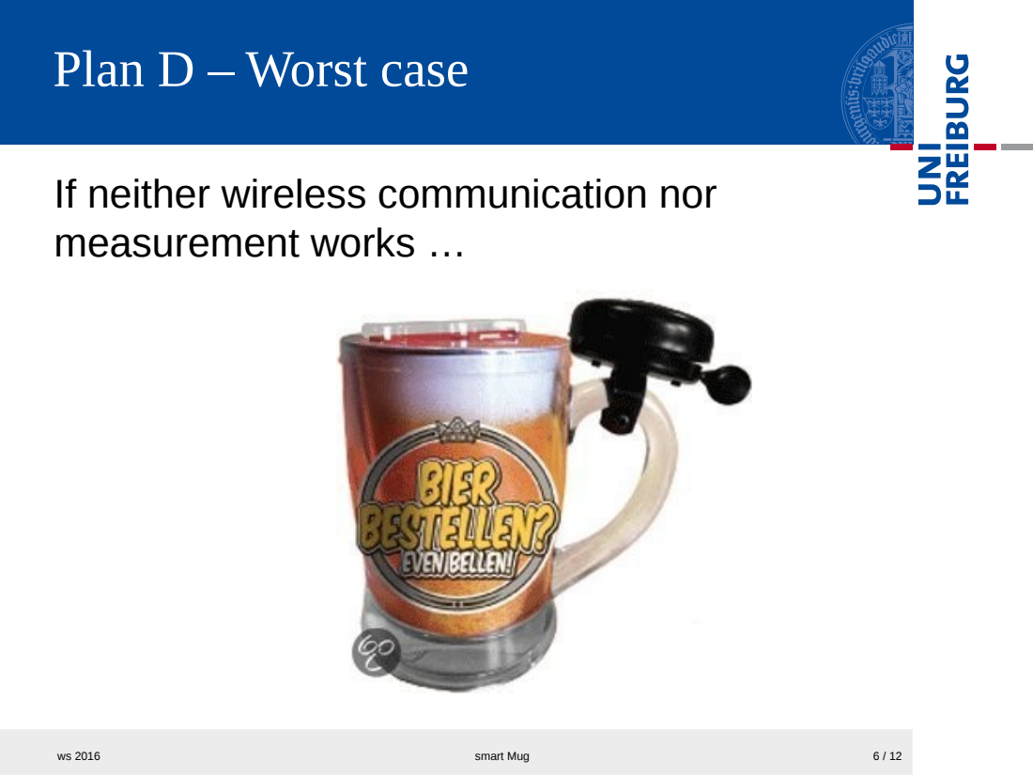
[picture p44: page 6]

If neither wireless communication nor
measurement works …

### Next steps / work plan

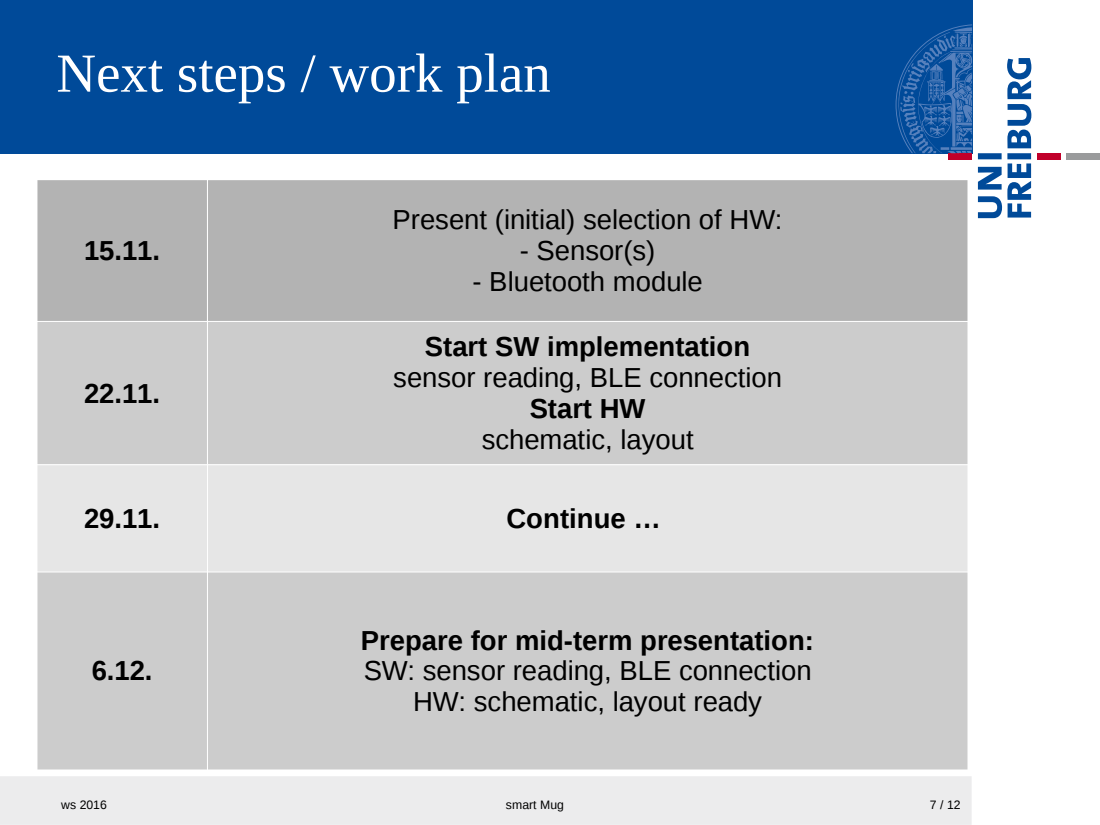
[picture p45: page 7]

15.11. | Present (initial) selection of HW: - Sensor(s) - Bluetooth module

22.11. | Start SW implementation sensor reading, BLE connection Start HW schematic, layout

29.11. Continue …

6.12. | Prepare for mid-term presentation: SW: sensor reading, BLE connection HW: schematic, layout ready

### Next steps / work plan

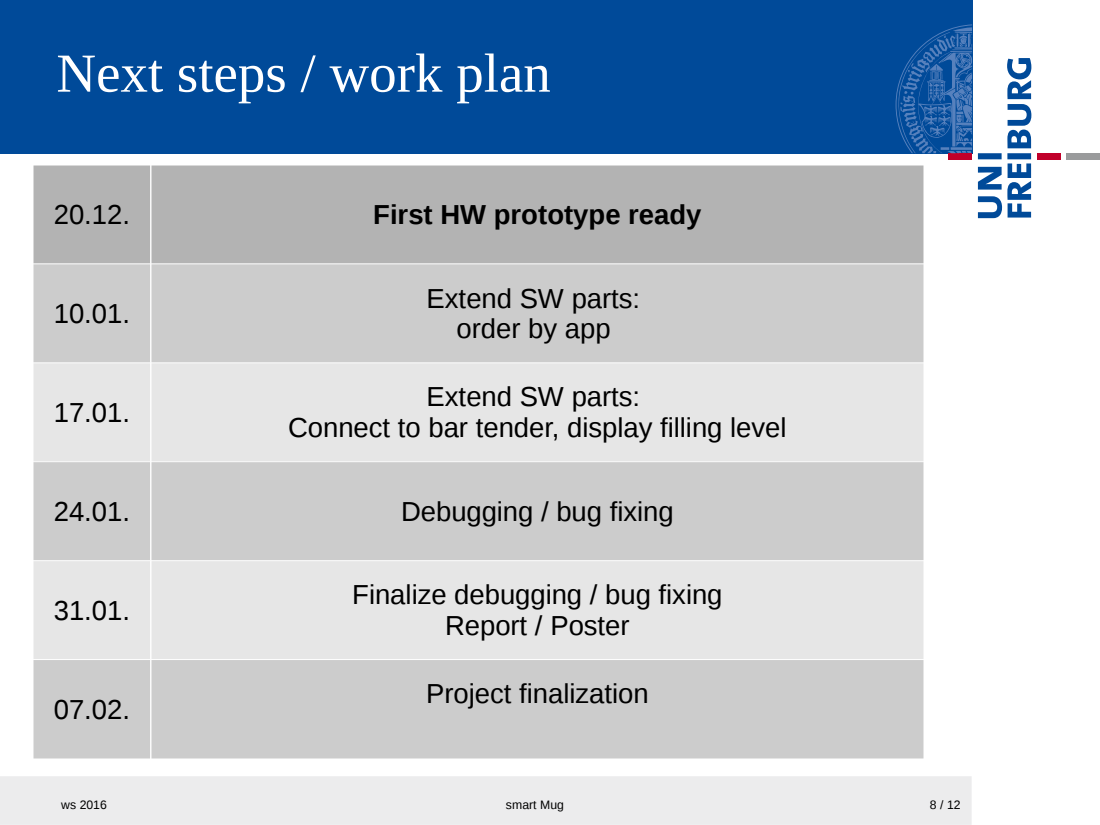
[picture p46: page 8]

20.12. First HW prototype ready

10.01. Extend SW parts: | order by app

17.01. Extend SW parts: | Connect to bar tender, display filling level

24.01. Debugging / bug fixing

31.01. Finalize debugging / bug fixing | Report / Poster

07.02. Project finalization

### Related work

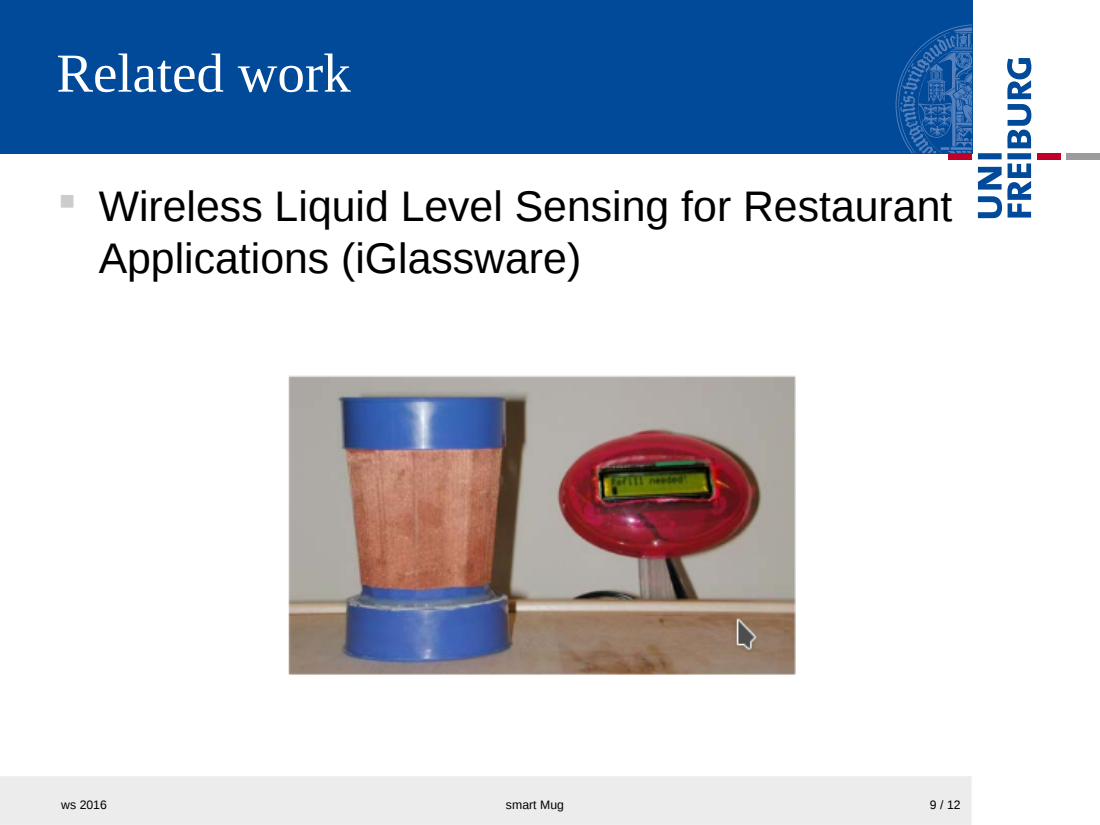
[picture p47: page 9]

§ Wireless Liquid Level Sensing for Restaurant
Applications (iGlassware)

### Related work

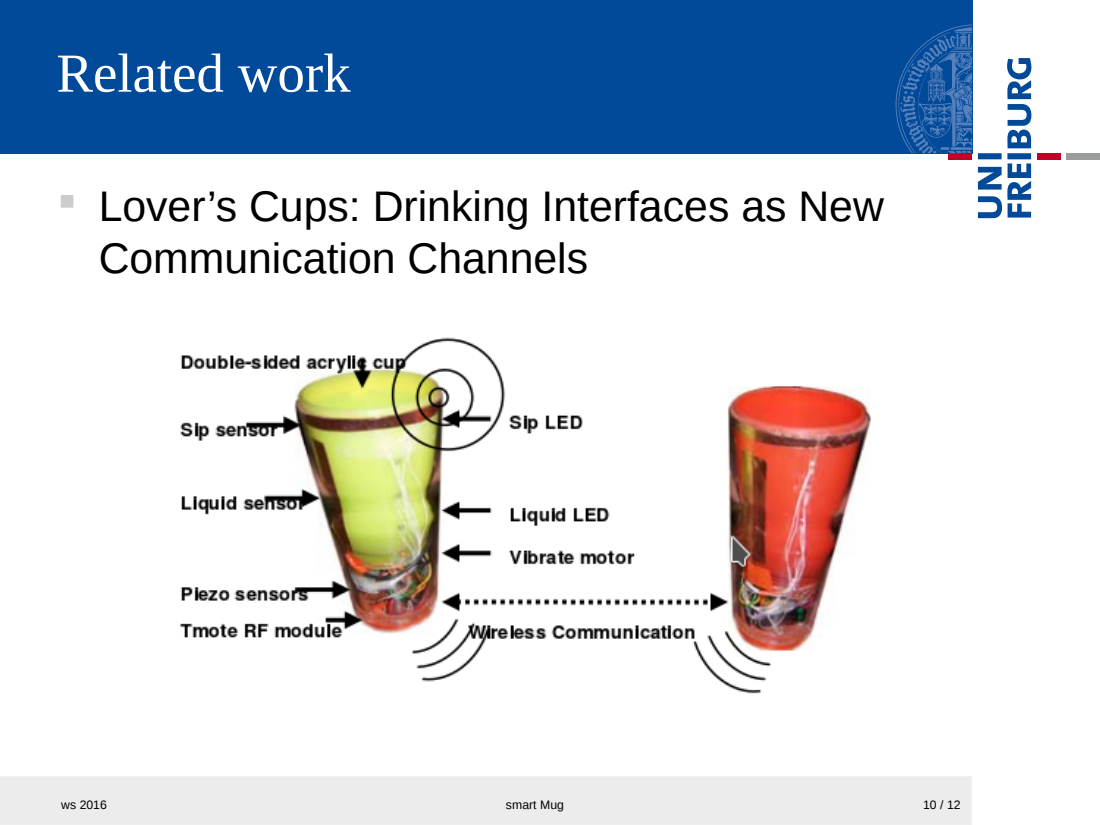
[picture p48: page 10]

§ Lover’s Cups: Drinking Interfaces as New
Communication Channels

### Appendix

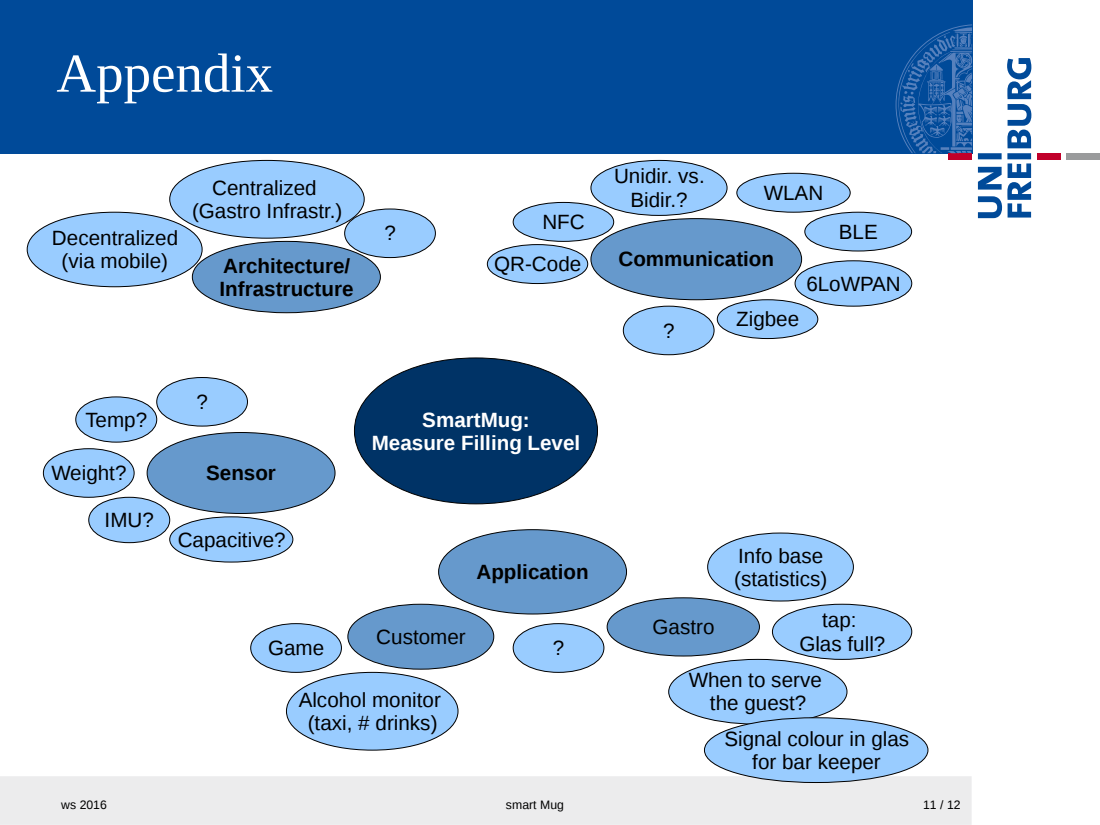
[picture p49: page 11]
Unidir. vs. Bidir.?; Decentralized (via mobile); Centralized (Gastro Infrastr.); Game; Alcohol monitor (taxi, # drinks); tap:; Customer; Glas full?; Gastro; Info base (statistics); WLAN; Application; Architecture/ Infrastructure; Communication; 6LoWPAN; BLE; Zigbee; Sensor; IMU?; Weight?; Temp?; Capacitive?; NFC; QR-Code

SmartMug:
Measure Filling Level

When to serve
the guest?
Signal colour in glas
for bar keeper

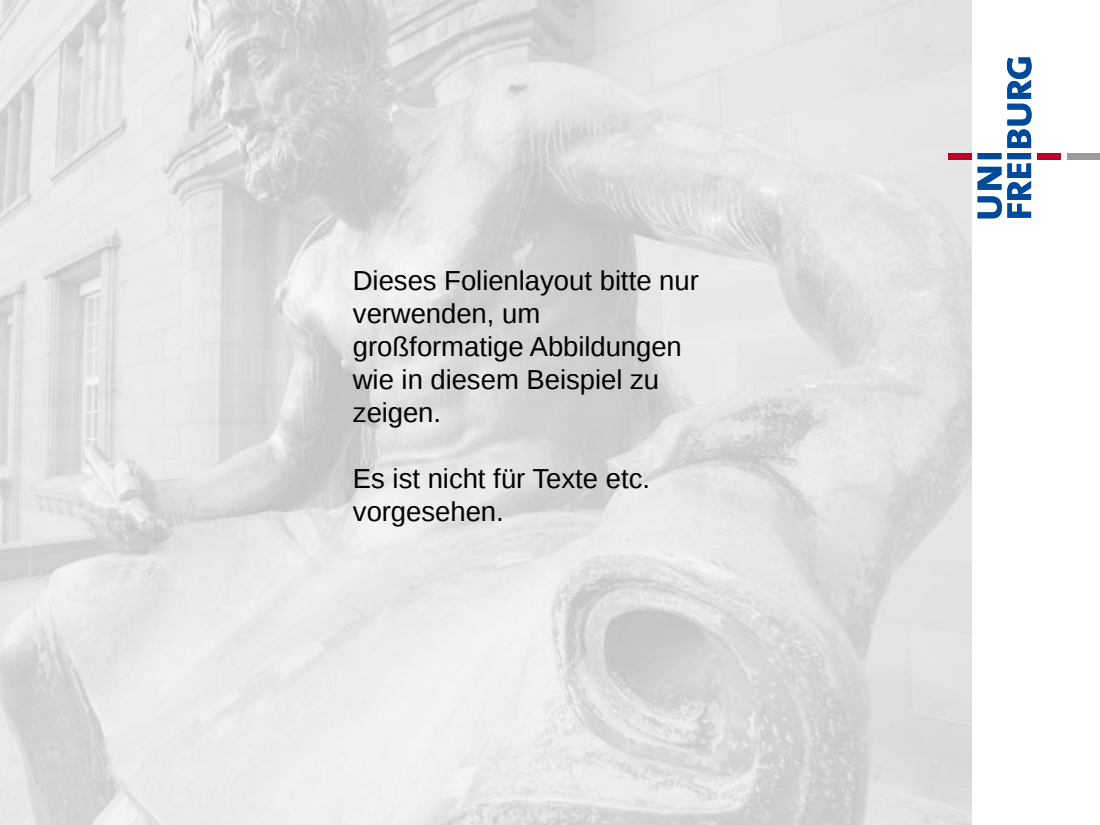
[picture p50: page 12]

Dieses Folienlayout bitte nur
verwenden, um
großformatige Abbildungen
wie in diesem Beispiel zu
zeigen.

Es ist nicht für Texte etc.
vorgesehen.

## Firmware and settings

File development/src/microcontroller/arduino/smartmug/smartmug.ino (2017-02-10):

/*! @file  smartmug.ino
 *  @brief This is the main() sketch of the smartmug project.
 *
 *  @defgroup arduino Arduino Code
 *  @brief Arduino code of the smartmug firmware.
 *
 *  @defgroup main SmartMug Main
 *  @brief Main entry of the smartmug firmware.
 *
 *  @addtogroup arduino
 *  @{
 *
 *  @addtogroup main
 *  @{
 */


/* === Global defines === */

/*! @brief Enables/disables debug prints. Debug is enabled if this macro is defined. */
#define DEBUG

/*! @brief Timeout that defines the period (in milliseconds) when new TCP data is sent. */
#define TCP_SEND_TIMEOUT_MS   1000
/*! @brief Defines if dummy data shall be sent or not. Set to '1' for sending dummy data. */
#define SEND_DUMMY_DATA       0

/* === Global variables === */

/*! @brief Timer for sending TCP data periodically. */
unsigned long tcpSendTimer;

/*! @brief First weight sensor data package defined by the smartmug group.
 *
 *  The data follows the first version of the smartmug protocol by sending:\n
 *  - TAG:   0x01 (Smartmug sensor data)\n
 *  - LEN:   0x02 (Two bytes of sensor data)\n
 *  - VALUE: two byte weight (in g) as unsigned int with MSB first\n
 *  - EOF:   '\\n' (0x0A) to allow easy data reading in Andriod app\n
 */
uint8_t tcpSensorData[] = {0x01, 0x02, 0x00, 0x00, 0x0A};

/*! Last weight that was measured. */
int currentWeight;

/* === Local/private function prototypes === */

/*!
 * @brief Main setup function of this ino firmware.
 */
void setup()
{
  // Setup serial connection for debugging purpose.
  serial_setup();

  // Setup the wifi connection.
  wifi_setup();

  // Setup over-the-air update
  ota_setup();

  // Setup multicast DNS
  mdns_setup();

  // Setup the TCP connection.
  tcp_setup();

  #if !SEND_DUMMY_DATA
  // Setup the HX711 for weight scaling
  hx711_setup();
  currentWeight = 0;
  #endif

  // Setup LEDs for operation
  led_setup();

  // Start a timer for sending TCP data periodically.
  tcpSendTimer = millis();

  Serial.println("\n###");
  Serial.println("Firmware setup complete. Entering main loop.");
  Serial.println("###");
}

/*!
 * @brief Main loop function of this ino firmware.
 */
void loop()
{
  // Handle WiFi connection.
  wifi_loop();

  // Handle over-the-air update
  ota_loop();

  // Handle multicast DNS
  mdns_loop();

  // Handle TCP connection.
  tcp_loop();

  #if !SEND_DUMMY_DATA
  // Handle the HX711
  hx711_loop();
  #endif

  // Send out TCP data periodically.
  if (millis() - tcpSendTimer > TCP_SEND_TIMEOUT_MS)
  {
    // Restart timer
    tcpSendTimer = millis();

    #if SEND_DUMMY_DATA
    if(currentWeight == 0)
    {
      currentWeight = 400;
    }
    else
    {
      currentWeight = currentWeight - 10;
    }

    #else
    /* Read sensor data */
    currentWeight = hx711_getWeightAsInt();
    #endif

    Serial.print("currentWeight: ");
    Serial.println(currentWeight);

    /* Set current weight (MSB first) */
    tcpSensorData[2] = highByte(currentWeight);
    tcpSensorData[3] = lowByte(currentWeight);
    tcp_send(tcpSensorData, sizeof(tcpSensorData));
  }
}


/* === Local utility functions starting here === */

/*!
 * @}
 * @}
 */

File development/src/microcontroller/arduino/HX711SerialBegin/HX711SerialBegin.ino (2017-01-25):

#include "HX711.h"

HX711 scale;
float result;

void setup() {
  Serial.begin(38400);
  Serial.println("HX711 Demo");

  Serial.println("Initializing the scale");
  // parameter "gain" is ommited; the default value 128 is used by the library
  // HX711.DOUT	- pin #A1
  // HX711.PD_SCK	- pin #A0
  scale.begin(14, 16);

  
  Serial.println("set_scale()");

  scale.set_scale();                      // this value is obtained by calibrating the scale with known weights; see the README for details
  scale.tare();				        // reset the scale to 0

  Serial.println("Place weight!");
  delay(5000);
  Serial.println("get_units(10)");
  result = scale.get_units(10);
  Serial.printf("get_units(10) result: ");
  Serial.println(result);
  result = result / 139;
  Serial.print("get_units(10) result/150: ");
  Serial.println(result);
  Serial.println("Remove weight!");
  delay(5000);

  Serial.print("set_scale() value = ");
  Serial.println(result);
  scale.set_scale(result);

  Serial.println("After setting up the scale:");

  Serial.print("read: \t\t");
  Serial.println(scale.read());                 // print a raw reading from the ADC

  Serial.print("read average: \t\t");
  Serial.println(scale.read_average(20));       // print the average of 20 readings from the ADC

  Serial.print("get value: \t\t");
  Serial.println(scale.get_value(5));		// print the average of 5 readings from the ADC minus the tare weight, set with tare()

  Serial.print("get units: \t\t");
  Serial.println(scale.get_units(5), 1);        // print the average of 5 readings from the ADC minus tare weight, divided
						// by the SCALE parameter set with set_scale

  Serial.println("Readings:");
}

void loop() {
  Serial.print("one reading:\t");
  Serial.print(scale.get_units(), 1);
  Serial.print("\t| average:\t");
  Serial.println(scale.get_units(10), 1);

  scale.power_down();			        // put the ADC in sleep mode
  delay(2000);
  scale.power_up();
}

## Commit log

2016-11-18 smartmug.ino: added empty main() sketch for arduino microcontroller development
2016-11-18 arduino: added serial.ino including serial_setup() and init from main()
2016-11-18 arduino: added empty wifi.ino and call wifi_setup() from main setup()
2016-11-18 arduino: added wifi_scan() and print results to get a feeling for the smartmug environment
2016-11-18 arduino: wifi_scan() now checks for the SSID to connect to and prints debug info
2016-11-18 arduino: added wifi_connect() to connect to user defined SSID
2016-11-18 arduino: make debug print of serial_setup() a little bit more readable.
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2016-11-18 arduino: count and display wifi connection time in wifi_connect()
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2016-11-18 arduino: init TCP session successfully. Tested using test-tcp.sh
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2016-11-18 arduino: added transmission of dummy data once a second using tcp_send()
2016-11-18 arduino: added server to allow tcp reception. Successfully tested using netcat.
2016-11-18 test-tcp-send.sh: added script to send some dummy data to the arduino
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2016-11-18 doxygen: added group arduino and subgroups for the module. Little doxy docu cleanup.
2016-11-19 arduino: added debug.ino including some macros for debug printing through serial/UART
2016-11-19 arduino: enable debug prints for this project as we are in development phase
2016-11-19 arduino: serial is initialized only if DEBUG is enabled. Start using DEBUG macros.
2016-11-19 arduino: more precise doxygen docu for debugging behaviour
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2016-11-22 capacitive sensor gerber files
    [TIDA_00317.GBL, TIDA_00317.GBO, TIDA_00317.GBP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]
2016-11-22 arduino: restart after 3sec if wifi SSID is not found
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2016-11-24 arduino: seems that mDNS works better if hostname is set by OTA for whatever reason.
    For now keep these lines for debugging. Basically, mDNS still working
2016-11-24 test/arduino: added script to parse mDNS service queries and print smartmug IP addr and port
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2016-11-29 arduino: added hx711 demo sketch; changed scaling pins to 15, 16; reduced measurement delay to 2000
2016-12-05 arduino: updated dummy data to follow first version of smartmug protocol
2016-12-05 arduino: kicked out active TCP client connection; only run server port and wait for incomming connections
    This also deletes hardcoded IP address handling.
2016-12-05 arduino: improved checking for remote connection in TCP server implementation
2016-12-05 arduino: display listener port number on serial console for debugging
2016-12-05 arduino: allow new connection after we got "WIFI_EVENT_STAMODE_GOT_IP" in wifi_eventHandler()
    This is the first workaround. We need to clarify why the TCP connection gets
    lost periodically.
    [tcp.ino, wifi.ino]
2016-12-05 arduino/test: added new empty script used to display smartmug sensor data
2016-12-05 arduino: switch smartmug server port to 8080 for now
2016-12-05 arduino/test: start tcp connection to smartmug, for still using hardcoded IP address
    This is a test script, so hardcoded IP is fine for now. Can later be combined
    with mDNS script support.
2016-12-05 arduino/smartmug.ota: (quick) fixed mDNS issue when requesting ESP.getChipId()
    [ota.ino]
2016-12-05 arduino/test: use correct remote port 8080 in script
2016-12-05 arduino/test: improve HEX dump in command line using xxd
2016-12-06 arduino: added empty hx711.ino sketch to smartmug project
2016-12-06 arduino: first integration of hx711 into smartmug. Code not tested, but compiling fine.
2016-12-06 arduino: add return to mpty loop()s and fixed comments
    [mdns.ino, wifi.ino]
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2016-12-13 arduino: added initial version of led.ino; not tested yet
2016-12-13 arduino: successfully added LED blinking in R, G, B; code requires cleanup
2016-12-14 arduino: added Red LED ON when TCP connection is established, OFF otherwise
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2016-12-14 arduino: removed LED debug code; read weight as int and send it through TCP socket
2016-12-14 arduino: hx711 ino now ensures that minimum weight read is 0 and never negative
2016-12-14 arduino: fixed length byte in sensorData message; restructured main loop a little
    [smartmug.ino]
2016-12-14 arduino: refactored LED API; updated calls in TCP ino
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2016-12-18 demo: parser debug print cleanup, display parsed message
2016-12-19 arduino: added debug prints when reading command to set LED to specific color
2016-12-19 arduino: use static IP address 192.168.5.10 as workaround for DLInk router issue
    [wifi.ino]
2016-12-19 arduino: adjust dummy data to be sent, use variable "currentWeight" for dummy data
2016-12-20 test: added sending of LED commands to script
2016-12-24 SolidWorks Parts for mug mounting on load cell
    [femalePart.SLDPRT, malePart.SLDPRT]
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2016-12-26 update :P
    [femalePart.SLDPRT, malePart.SLDPRT]
2017-01-17 ConnectionActivity: delete obsolete debug print. refactore this class!
2017-01-17 arduino: fix issue with reading TCP data by cleaning RX data after handling it
    [tcp.ino]
2017-01-21 app: added service discovery triggered by app start
    Unfortunately, no services where ever found using the Android Emulator. Test
    on real device is pending. Using wireshark, the MDNS requests from PC was
    detected as well as MDNS response from Arduino. However, the NsdHelper internal
    function onServiceFound() is never called.
    According to debug cmd line output the discovery process is started but no
    results are found at all.
    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
2017-01-25 docu: added section arduino pinout section to readme.md
2017-01-28 java-docu: fixed java doxy group that had same name as arduino doxy group
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2017-02-01 led: changed LED pin out according to final smartmug HW layout, adapted docu accordingly
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2017-02-03 arduino-tcp: send data in single write() call for the sake of efficiency
2017-02-07 Hardware and Design updates
    [boden.SLDPRT, boden.STL, deckel.SLDPRT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]
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2017-02-10 doxy docu: added missing doxygen groups for arduino mdns and ota modules
    [mdns.ino, ota.ino]
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2017-02-10 Some updates in the case
    [Unterlagscheibe.SLDPRT, Unterlagscheibe4.STL, Unterlagscheibe8.STL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]
2017-02-10 arduino: updated doxygen docu for arduino code and added missing descriptions
    [hx711.ino, led.ino, mdns.ino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]
